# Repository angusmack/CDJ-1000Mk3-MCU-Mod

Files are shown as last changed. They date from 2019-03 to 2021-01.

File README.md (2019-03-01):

# Overview

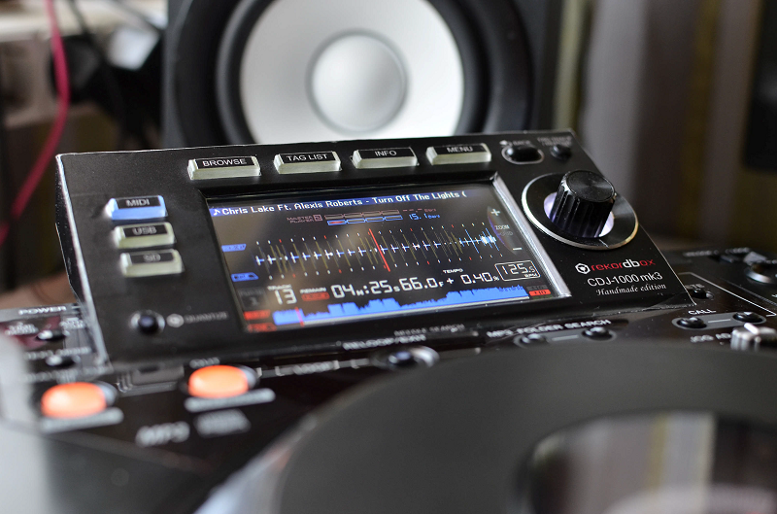
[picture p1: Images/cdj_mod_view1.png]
CDJ1000Mk3 MCU Mod


This is a modification to the CDJ-1000mk3 using an MCU, which allows SD-card playback of WAV files.

This firmware is for the F7 chip on the 32F746G DISCOVERY board.

This project was originally started by Andrei (DJ Greeb) in the [https://github.com/djgreeb/CDJ-1000mk3_new_life_project](repo).

This mod supports some Rekordbox functions, displaying of static and dynamic waveforms, audio interpolation process. 

I (Angus) have taken over the support of hosting the source code (that Andrei shared recently) and sharing the other supporting files needed such as STL and PCB for creating the finished product 

# Building the source
Use IDE uVision Keil ARM-MDK Professional and open project file F7.uvprojx in MDK_ARM folder.

Make sure you cut the tracks ULPI_1 and 13 as specified in the build manual before flashing.

# To do:
- AIFF support
- MP3 support
- USB playback
- Hot cues
- ?

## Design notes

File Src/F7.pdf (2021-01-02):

## F7 Project Configuration Report

# 1. Description

## 1.1. Project

Project Name | F7
Board Name | STM32F746G-DISCO
Generated with: | STM32CubeMX 4.22.0
Date | 04/26/2020

## 1.2. MCU

MCU Series | STM32F7
MCU Line | STM32F7x6
MCU name | STM32F746NGHx
MCU Package | TFBGA216
MCU Pin number | 216

# 2. Pinout Configuration

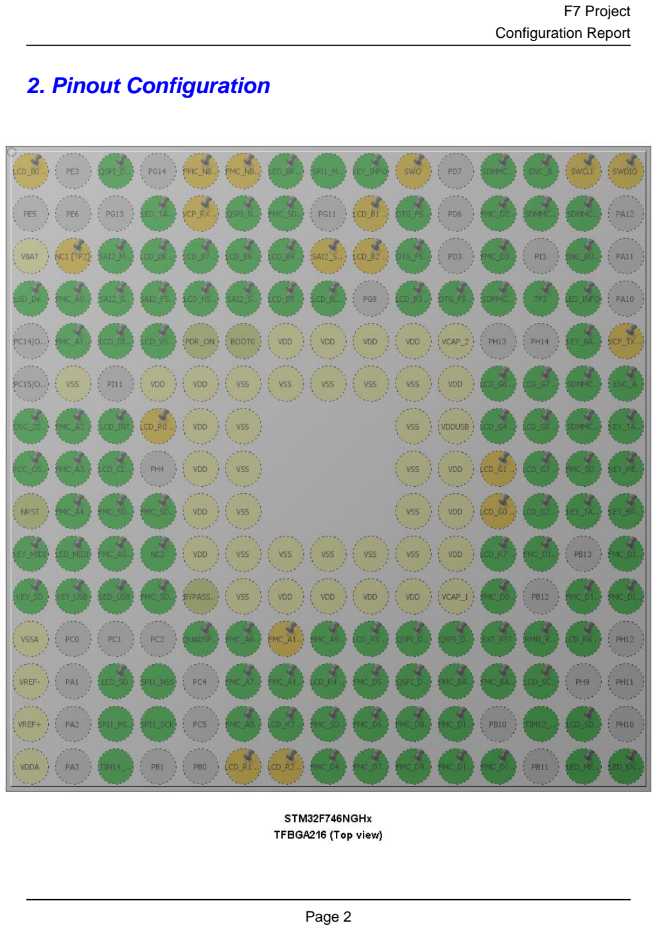
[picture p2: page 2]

# 3. Pins Configuration

Pin Number TFBGA216 | Pin Name (function after reset) | Pin Type | Alternate Function(s) | Label
A1 | PE4 * | I/O | LTDC_B0 | LCD_B0 [RK043FN48H-CT672B_B0]
A3 | PE2 | I/O | QUADSPI_BK1_IO2 | QSPI_D2 [N25Q128A13EF840E_DQ2 ]
A5 | PE1 * | I/O | FMC_NBL1 | FMC_NBL1 [MT48LC4M32B2B5-6A_DQM1]
A6 | PE0 * | I/O | FMC_NBL0 | FMC_NBL0 [MT48LC4M32B2B5-6A_DQM0]
A7 | PB8 ** | I/O | GPIO_Output | LED_BROWSE
A8 | PB5 | I/O | SPI1_MOSI
A9 | PB4 ** | I/O | GPIO_Input | KEY_INFO
A10 | PB3 * | I/O | SYS_JTDO-SWO | SWO
A12 | PC12 | I/O | SDMMC1_CK | SDMMC_CK
A13 | PA15 | I/O | GPIO_EXTI15 | ENC_B
A14 | PA14 * | I/O | SYS_JTCK-SWCLK | SWCLK
A15 | PA13 * | I/O | SYS_JTMS-SWDIO | SWDIO
B4 | PB9 ** | I/O | GPIO_Output | LED_TAG_LIST
B5 | PB7 * | I/O | USART1_RX | VCP_RX [STM32F103CBT6_PA2]
B6 | PB6 | I/O | QUADSPI_BK1_NCS | QSPI_NCS [N25Q128A13EF840E_S]
B7 | PG15 | I/O | FMC_SDNCAS | FMC_SDNCAS [MT48LC4M32B2B5-6A_CAS]
B9 | PJ13 * | I/O | LTDC_B1 | LCD_B1 [RK043FN48H-CT672B_B1]
B10 | PJ12 ** | I/O | GPIO_Input | OTG_FS_VBUS
B12 | PD0 | I/O | FMC_D2 | FMC_D2 [MT48LC4M32B2B5-6A_DQ2]
B13 | PC11 | I/O | SDMMC1_D3 | SDMMC_D3
B14 | PC10 | I/O | SDMMC1_D2 | SDMMC_D2
C1 | VBAT | Power
C2 | PI8 * | I/O | RTC_TS | NC1 [TP2]
C3 | PI4 | I/O | SAI2_MCLK_A | SAI2_MCLKA [WM8994ECS/R_MCLK1]

Pin Number TFBGA216 | Pin Name (function after reset) | Pin Type | Alternate Function(s) | Label
C4 | PK7 | I/O | LTDC_DE | LCD_DE [RK043FN48H-CT672B_DE]
C5 | PK6 | I/O | LTDC_B7 | LCD_B7 [RK043FN48H-CT672B_B7]
C6 | PK5 | I/O | LTDC_B6 | LCD_B6 [RK043FN48H-CT672B_B6]
C7 | PG12 | I/O | LTDC_B4 | LCD_B4 [RK043FN48H-CT672B_B4]
C8 | PG10 * | I/O | SAI2_SD_B | SAI2_SDB [WM8994ECS/R_ADCDAT1 ]
C9 | PJ14 * | I/O | LTDC_B2 | LCD_B2 [RK043FN48H-CT672B_B2]
C10 | PD5 ** | I/O | GPIO_Output | OTG_FS_PowerSwitchOn [STMPS2141STR_EN]
C12 | PD1 | I/O | FMC_D3 | FMC_D3 [MT48LC4M32B2B5-6A_DQ3]
C14 | PI2 ** | I/O | GPIO_Input | ENC_BUTTON
D1 | PC13 ** | I/O | GPIO_Input | uSD_Detect
D2 | PF0 | I/O | FMC_A0 | FMC_A0 [MT48LC4M32B2B5-6A_A0]
D3 | PI5 | I/O | SAI2_SCK_A | SAI2_SCKA [WM8994ECS/R_BCLK1]
D4 | PI7 | I/O | SAI2_FS_A | SAI2_FSA [WM8994ECS/R_LRCLK1]
D5 | PI10 | I/O | LTDC_HSYNC | LCD_HSYNC [RK043FN48H-CT672B_HSYNC]
D6 | PI6 | I/O | SAI2_SD_A | SAI2_SDA [WM8994ECS/R_DACDAT1 ]
D7 | PK4 | I/O | LTDC_B5 | LCD_B5 [RK043FN48H-CT672B_B5]
D8 | PK3 ** | I/O | GPIO_Output | LCD_BL_CTRL [STLD40DPUR_EN]
D10 | PJ15 | I/O | LTDC_B3 | LCD_B3 [RK043FN48H-CT672B_B3]
D11 | PD4 ** | I/O | GPIO_Input | OTG_FS_OverCurrent [STMPS2141STR_Fault]
D12 | PD2 | I/O | SDMMC1_CMD | SDMMC_D0
D13 | PH15 ** | I/O | GPIO_Input | TP3
D14 | PI1 ** | I/O | GPIO_Output | LED_INFO

Pin Number TFBGA216 | Pin Name (function after reset) | Pin Type | Alternate Function(s) | Label
E2 | PF1 | I/O | FMC_A1 | FMC_A1 [MT48LC4M32B2B5-6A_A1]
E3 | PI12 ** | I/O | GPIO_Output | LCD_DISP [RK043FN48H-CT672B_DISP]
E4 | PI9 | I/O | LTDC_VSYNC | LCD_VSYNC [RK043FN48H-CT672B_VSYNC]
E5 | PDR_ON | Reset
E6 | BOOT0 | Boot
E7 | VDD | Power
E8 | VDD | Power
E9 | VDD | Power
E10 | VDD | Power
E11 | VCAP_2 | Power
E14 | PI0 ** | I/O | GPIO_Input | KEY_BACK
E15 | PA9 * | I/O | USART1_TX | VCP_TX [STM32F103CBT6_PA3]
F2 | VSS | Power
F4 | VDD | Power
F5 | VDD | Power
F6 | VSS | Power
F7 | VSS | Power
F8 | VSS | Power
F9 | VSS | Power
F10 | VSS | Power
F11 | VDD | Power
F12 | PK1 | I/O | LTDC_G6 | LCD_G6 [RK043FN48H-CT672B_G6]
F13 | PK2 | I/O | LTDC_G7 | LCD_G7 [RK043FN48H-CT672B_G7]
F14 | PC9 | I/O | SDMMC1_D1
F15 | PA8 ** | I/O | GPIO_Input | ENC_A
G1 | PH0/OSC_IN | I/O | RCC_OSC_IN | OSC_25M [NZ2520SB-25.00M_OUT]
G2 | PF2 | I/O | FMC_A2 | FMC_A2 [MT48LC4M32B2B5-6A_A2]
G3 | PI13 | I/O | GPIO_EXTI13 | LCD_INT
G4 | PI15 * | I/O | LTDC_R0 | LCD_R0 [RK043FN48H-CT672B_R0]
G5 | VDD | Power
G6 | VSS | Power

Pin Number TFBGA216 | Pin Name (function after reset) | Pin Type | Alternate Function(s) | Label
G10 | VSS | Power
G11 | VDDUSB | Power
G12 | PJ11 | I/O | LTDC_G4 | LCD_G4 [RK043FN48H-CT672B_G4]
G13 | PK0 | I/O | LTDC_G5 | LCD_G5 [RK043FN48H-CT672B_G5]
G14 | PC8 | I/O | SDMMC1_D0
G15 | PC7 ** | I/O | GPIO_Input | KEY_TAG_LIST
H1 | PH1/OSC_OUT | I/O | RCC_OSC_OUT
H2 | PF3 | I/O | FMC_A3 | FMC_A3 [MT48LC4M32B2B5-6A_A3]
H3 | PI14 | I/O | LTDC_CLK | LCD_CLK [RK043FN48H-CT672B_CLK]
H5 | VDD | Power
H6 | VSS | Power
H10 | VSS | Power
H11 | VDD | Power
H12 | PJ8 * | I/O | LTDC_G1 | LCD_G1 [RK043FN48H-CT672B_G1]
H13 | PJ10 | I/O | LTDC_G3 | LCD_G3 [RK043FN48H-CT672B_G3]
H14 | PG8 | I/O | FMC_SDCLK | FMC_SDCLK [MT48LC4M32B2B5-6A_CLK]
H15 | PC6 ** | I/O | GPIO_Input | KEY_MENU
J1 | NRST | Reset
J2 | PF4 | I/O | FMC_A4 | FMC_A4 [MT48LC4M32B2B5-6A_A4]
J3 | PH5 | I/O | FMC_SDNWE | FMC_SDNME [MT48LC4M32B2B5-6A_WE]
J4 | PH3 | I/O | FMC_SDNE0 | FMC_SDNE0 [MT48LC4M32B2B5-6A_CS]
J5 | VDD | Power
J6 | VSS | Power
J10 | VSS | Power
J11 | VDD | Power
J12 | PJ7 * | I/O | LTDC_G0 | LCD_G0 [RK043FN48H-CT672B_G0]
J13 | PJ9 | I/O | LTDC_G2 | LCD_G2 [RK043FN48H-CT672B_G2]

Pin Number TFBGA216 | Pin Name (function after reset) | Pin Type | Alternate Function(s) | Label
J14 | PG7 ** | I/O | GPIO_Input | KEY_TAG_TRACK
J15 | PG6 ** | I/O | GPIO_Input | KEY_BROWSE
K1 | PF7 ** | I/O | GPIO_Input | KEY_MIDI
K2 | PF6 ** | I/O | GPIO_Output | LED_MIDI
K3 | PF5 | I/O | FMC_A5 | FMC_A5 [MT48LC4M32B2B5-6A_A5]
K4 | PH2 ** | I/O | GPIO_Input | NC2
K5 | VDD | Power
K6 | VSS | Power
K7 | VSS | Power
K8 | VSS | Power
K9 | VSS | Power
K10 | VSS | Power
K11 | VDD | Power
K12 | PJ6 | I/O | LTDC_R7 | LCD_R7 [RK043FN48H-CT672B_R7]
K13 | PD15 | I/O | FMC_D1 | FMC_D1 [MT48LC4M32B2B5-6A_DQ1]
K15 | PD10 | I/O | FMC_D15 | FMC_D15 [MT48LC4M32B2B5-6A_DQ15]
L1 | PF10 ** | I/O | GPIO_Input | KEY_SD
L2 | PF9 ** | I/O | GPIO_Input | KEY_USB
L3 | PF8 ** | I/O | GPIO_Output | LED_USB
L4 | PC3 | I/O | FMC_SDCKE0 | FMC_SDCKE0 [MT48LC4M32B2B5-6A_CKE]
L5 | BYPASS_REG | Reset
L6 | VSS | Power
L7 | VDD | Power
L8 | VDD | Power
L9 | VDD | Power
L10 | VDD | Power
L11 | VCAP_1 | Power
L12 | PD14 | I/O | FMC_D0 | FMC_D0 [MT48LC4M32B2B5-6A_DQ0]
L14 | PD9 | I/O | FMC_D14 | FMC_D14 [MT48LC4M32B2B5-6A_DQ14]

Pin Number TFBGA216 | Pin Name (function after reset) | Pin Type | Alternate Function(s) | Label
L15 | PD8 | I/O | FMC_D13 | FMC_D13 [MT48LC4M32B2B5-6A_DQ13]
M1 | VSSA | Power
M5 | PB2 | I/O | QUADSPI_CLK
M6 | PF12 | I/O | FMC_A6 | FMC_A6 [MT48LC4M32B2B5-6A_A6]
M7 | PG1 * | I/O | FMC_A11 | FMC_A11 [MT48LC4M32B2B5-6A_A11]
M8 | PF15 | I/O | FMC_A9 | FMC_A9 [MT48LC4M32B2B5-6A_A9]
M9 | PJ4 | I/O | LTDC_R5 | LCD_R5 [RK043FN48H-CT672B_R5]
M10 | PD12 | I/O | QUADSPI_BK1_IO1 | QSPI_D1 [N25Q128A13EF840E_DQ1 ]
M11 | PD13 | I/O | QUADSPI_BK1_IO3 | QSPI_D3 [N25Q128A13EF840E_DQ3 ]
M12 | PG3 ** | I/O | GPIO_Output | EXT_RST
M13 | PG2 ** | I/O | GPIO_Input | RMII_RXER
M14 | PJ5 | I/O | LTDC_R6 | LCD_R6 [RK043FN48H-CT672B_R6]
N1 | VREF- | Power
N3 | PA0/WKUP ** | I/O | GPIO_Output | LED_SD
N4 | PA4 | I/O | SPI1_NSS
N6 | PF13 | I/O | FMC_A7 | FMC_A7 [MT48LC4M32B2B5-6A_A7]
N7 | PG0 | I/O | FMC_A10 | FMC_A10 [MT48LC4M32B2B5-6A_A10]
N8 | PJ3 | I/O | LTDC_R4 | LCD_R4 [RK043FN48H-CT672B_R4]
N9 | PE8 | I/O | FMC_D5 | FMC_D5 [MT48LC4M32B2B5-6A_DQ5]
N10 | PD11 | I/O | QUADSPI_BK1_IO0 | QSPI_D0 [N25Q128A13EF840E_DQ0 ]
N11 | PG5 | I/O | FMC_BA1 | FMC_BA1 [MT48LC4M32B2B5-6A_BA1]

Pin Number TFBGA216 | Pin Name (function after reset) | Pin Type | Alternate Function(s) | Label
N12 | PG4 | I/O | FMC_BA0 | FMC_BA0 [MT48LC4M32B2B5-6A_BA0]
N13 | PH7 | I/O | I2C3_SCL | LCD_SCL [RK043FN48H-CT672B_SCL]
P1 | VREF+ | Power
P3 | PA6 | I/O | SPI1_MISO
P4 | PA5 | I/O | SPI1_SCK
P6 | PF14 | I/O | FMC_A8 | FMC_A8 [MT48LC4M32B2B5-6A_A8]
P7 | PJ2 | I/O | LTDC_R3 | LCD_R3 [RK043FN48H-CT672B_R3]
P8 | PF11 | I/O | FMC_SDNRAS | FMC_SDNRAS [MT48LC4M32B2B5-6A_RAS]
P9 | PE9 | I/O | FMC_D6 | FMC_D6 [MT48LC4M32B2B5-6A_DQ6]
P10 | PE11 | I/O | FMC_D8 | FMC_D8 [MT48LC4M32B2B5-6A_DQ8]
P11 | PE14 | I/O | FMC_D11 | FMC_D11 [MT48LC4M32B2B5-6A_DQ11]
P13 | PH6 | I/O | TIM12_CH1
P14 | PH8 | I/O | I2C3_SDA | LCD_SDA [RK043FN48H-CT672B_SDA]
R1 | VDDA | Power
R3 | PA7 | I/O | TIM14_CH1
R6 | PJ0 * | I/O | LTDC_R1 | LCD_R1 [RK043FN48H-CT672B_R1]
R7 | PJ1 * | I/O | LTDC_R2 | LCD_R2 [RK043FN48H-CT672B_R2]
R8 | PE7 | I/O | FMC_D4 | FMC_D4 [MT48LC4M32B2B5-6A_DQ4]
R9 | PE10 | I/O | FMC_D7 | FMC_D7 [MT48LC4M32B2B5-6A_DQ7]
R10 | PE12 | I/O | FMC_D9 | FMC_D9 [MT48LC4M32B2B5-6A_DQ9]

Pin Number TFBGA216 | Pin Name (function after reset) | Pin Type | Alternate Function(s) | Label
R11 | PE15 | I/O | FMC_D12 | FMC_D12 [MT48LC4M32B2B5-6A_DQ12]
R12 | PE13 | I/O | FMC_D10 | FMC_D10 [MT48LC4M32B2B5-6A_DQ10]
R14 | PB14 ** | I/O | GPIO_Output | LED_MENU
R15 | PB15 ** | I/O | GPIO_Output | LED_ENCODER

## ** The pin is affected with an I/O function * The pin is affected with a peripheral function but no peripheral mode is activated

# 4. Clock Tree Configuration

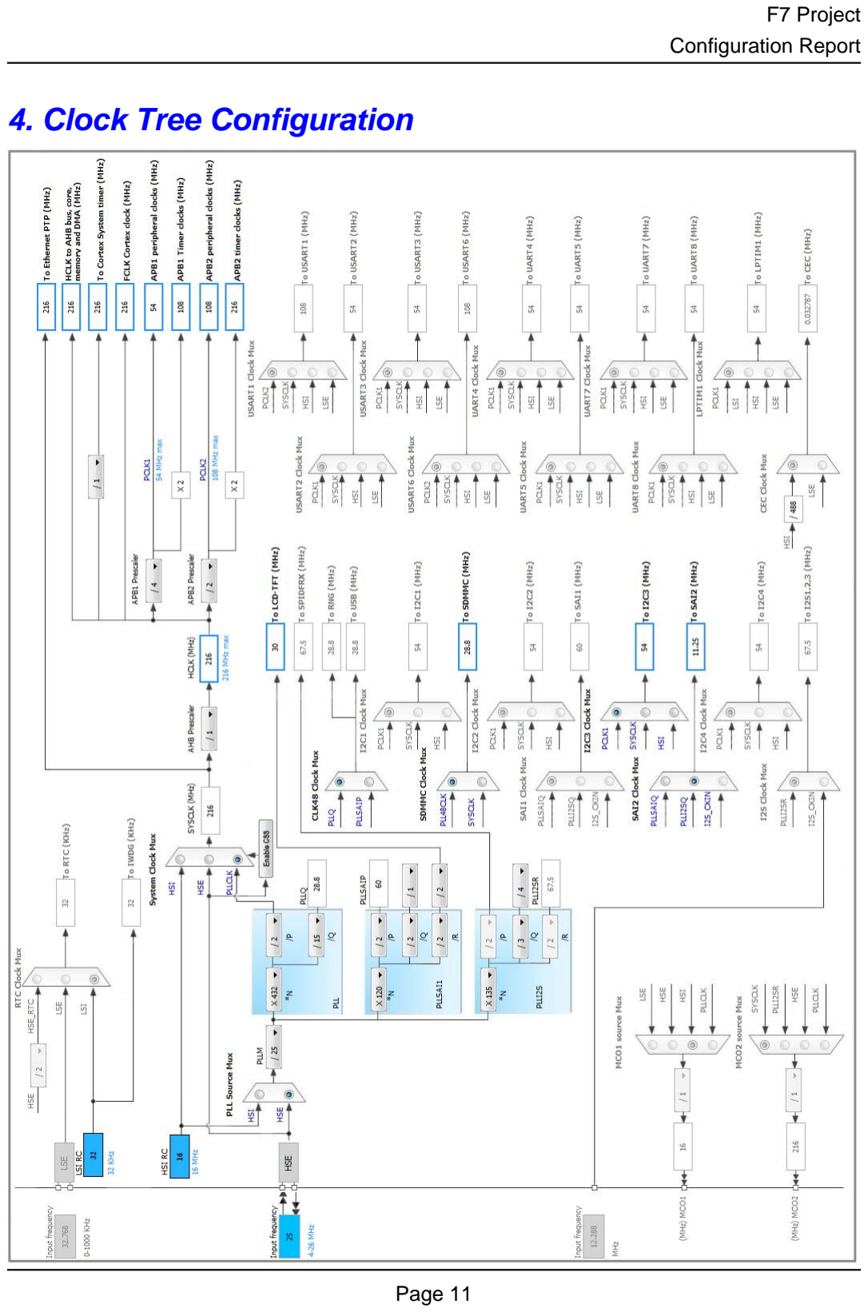
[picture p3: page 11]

# 5. IPs and Middleware Configuration

# 5.1. DMA2D

## mode: Activated

## 5.1.1. Parameter Settings:

### Basic Parameters:

Transfer Mode | Memory to Memory
Color Mode | ARGB8888
Output Offset | 0

### Foreground layer Configuration:

DMA2D Input Color Mode | ARGB8888
DMA2D ALPHA MODE | No modification of the alpha channel value
Input Alpha | 0
Input Offset | 0
DMA2D ALPHA Inversion | Regular Alpha
DMA2D Red and Blue swap | Regular mode (RGB or ARGB)

# 5.2. FMC

## SDRAM 1

## Clock and chip enable: SDCKE0+SDNE0 Internal bank number: 4 banks Address: 11 bits Data: 16 bits

## 5.2.1. SDRAM 1:

### SDRAM control:

Bank | SDRAM bank 1
Number of column address bits | 8 bits
Number of row address bits | 11 bits
CAS latency | 2 memory clock cycles *
Write protection | Disabled
SDRAM common clock | Disabled
SDRAM common burst read | Enabled *

SDRAM common read pipe delay | 0 HCLK clock cycle

### SDRAM timing in memory clock cycles:

Load mode register to active delay | 2 *
Exit self-refresh delay | 6 *
Self-refresh time | 4 *
SDRAM common row cycle delay | 6 *
Write recovery time | 2 *
SDRAM common row precharge delay | 2 *
Row to column delay | 2 *

# 5.3. I2C3

## I2C: I2C

## 5.3.1. Parameter Settings:

### Timing configuration:

I2C Speed Mode | Standard Mode
I2C Speed Frequency (KHz) | 100
Rise Time (ns) | 0
Fall Time (ns) | 0
Coefficient of Digital Filter | 0
Analog Filter | Enabled
Timing | 0x20404768 *

### Slave Features:

Clock No Stretch Mode | Disabled
General Call Address Detection | Disabled
Primary Address Length selection | 7-bit
Dual Address Acknowledged | Disabled
Primary slave address | 0

# 5.4. LTDC

## Display Type: RGB565 (16 bits)

## 5.4.1. Parameter Settings:

### Synchronization for Width:

Horizontal Synchronization Width | 41 *
Horizontal Back Porch | 13 *
Active Width | 480 *
Horizontal Front Porch | 32 *
HSync Width | 40
Accumulated Horizontal Back Porch Width | 53
Accumulated Active Width | 533
Total Width | 565

### Synchronization for Height:

Vertical Synchronization Height | 10 *
Vertical Back Porch | 2
Active Height | 272 *
Vertical Front Porch | 2
VSync Height | 9
Accumulated Vertical Back Porch Height | 11
Accumulated Active Height | 283
Total Height | 285

### Signal Polarity:

Horizontal Synchronization Polarity | Active Low
Vertical Synchronization Polarity | Active Low
Data Enable Polarity | Active Low
Pixel Clock Polarity | Normal Input

### BackGround Color:

Red | 0
Green | 0
Blue | 0

## 5.4.2. Layer Settings:

### BackGround Color:

Layer 0 - Blue | 0
Layer 0 - Green | 0
Layer 0 - Red | 0
Layer 1 - Blue | 0
Layer 1 - Green | 0
Layer 1 - Red | 0

### Windows Position:

Layer 0 - Window Horizontal Start | 0

Layer 0 - Window Horizontal Stop | 480 *
Layer 0 - Window Vertical Start | 0
Layer 0 - Window Vertical Stop | 272 *
Layer 1 - Window Horizontal Start | 0
Layer 1 - Window Horizontal Stop | 480 *
Layer 1 - Window Vertical Start | 0
Layer 1 - Window Vertical Stop | 272 *

### Pixel Parameters:

Layer 0 - Pixel Format | ARGB8888
Layer 1 - Pixel Format | ARGB8888

### Blending:

Layer 0 - Alpha constant for blending | 255 *
Layer 0 - Default Alpha value | 0
Layer 0 - Blending Factor1 | Alpha constant
Layer 0 - Blending Factor2 | Alpha constant
Layer 1 - Alpha constant for blending | 255 *
Layer 1 - Default Alpha value | 0
Layer 1 - Blending Factor1 | Alpha constant
Layer 1 - Blending Factor2 | Alpha constant

### Frame Buffer:

Layer 0 - Color Frame Buffer Start Adress | 0
Layer 0 - Color Frame Buffer Line Length (Image Width) | 0
Layer 0 - Color Frame Buffer Number of Lines (Image Height) | 0
Layer 1 - Color Frame Buffer Start Adress | 0
Layer 1 - Color Frame Buffer Line Length (Image Width) | 0
Layer 1 - Color Frame Buffer Number of Lines (Image Height) | 0

### Number of Layers:

Number of Layers | 2 layers

# 5.5. QUADSPI

## QuadSPI Mode: Bank1 with Quad SPI Lines

## 5.5.1. Parameter Settings:

### General Parameters:

Clock Prescaler | 1 *
Fifo Threshold | 4 *
Sample Shifting | Sample Shifting Half Cycle *
Flash Size | 23 *
Chip Select High Time | 2 Cycles *
Clock Mode | Low
Flash ID | Flash ID 1
Dual Flash | Disabled

# 5.6. RCC

## High Speed Clock (HSE): Crystal/Ceramic Resonator

## 5.6.1. Parameter Settings:

### System Parameters:

VDD voltage (V) | 3.3
Flash Latency(WS) | 7 WS (8 CPU cycle)

### RCC Parameters:

HSI Calibration Value | 16
TIM Prescaler Selection | Disabled
HSE Startup Timout Value (ms) | 100
LSE Startup Timout Value (ms) | 5000

### Power Parameters:

Power Over Drive | Enabled
Power Regulatror Voltage Scale | Power Regulator Voltage Scale 1

# 5.7. SAI2

## Mode: Master with Master Clock Out

## 5.7.1. Parameter Settings:

### SAI A:

Basic Parameters
Protocol | Free
Audio Mode | Master Transmit
Frame Length | 64 bits *

Data Size | 16 Bits *
Slot Size | DataSize
Output Mode | Stereo
Companding Mode | No companding mode
SAI SD Line Output Mode | Driven
Frame Parameters
First Bit | MSB First
Frame Synchro Active Level Length | 1
Frame Synchro Definition | Channel Identification *
Frame Synchro Polarity | Active Low
Frame Synchro Offset | Before First Bit *

Slot Parameters
First Bit Offset | 0
Number of Slots (only Even Values) | 2
Slot Active Final Value | 0x00000003 *
Slot Active | User Setting *
Slot 0 Active | true *
Slot 1 Active | true *

Clock Parameters
Master Clock Divider | Enabled
Audio Frequency | 44.1 KHz *
Real Audio Frequency | 43.945 KHz *
Error between Selected | -77.11 % *
Clock Strobing | Rising Edge *

Advanced Parameters
Fifo Threshold | Empty
Output Drive | Enabled *
Synchronization External | Disabled

# 5.8. SDMMC1

## Mode: SD 4 bits Wide bus

## 5.8.1. Parameter Settings:

### SDMMC parameters:

SDMMCCLK clock divide factor | 1 *

# 5.9. SPI1

## Mode: Full-Duplex Slave Hardware NSS Signal: Hardware NSS Input Signal

## 5.9.1. Parameter Settings:

### Basic Parameters:

Frame Format | Motorola
Data Size | 8 Bits *
First Bit | MSB First

### Clock Parameters:

Clock Polarity (CPOL) | High *
Clock Phase (CPHA) | 2 Edge *

### Advanced Parameters:

CRC Calculation | Disabled
NSS Signal Type | Input Hardware

# 5.10. SYS

## Timebase Source: SysTick

# 5.11. TIM1

## Clock Source : Internal Clock

## 5.11.1. Parameter Settings:

### Counter Settings:

Prescaler (PSC - 16 bits value) | 999 *
Counter Mode | Up
Counter Period (AutoReload Register - 16 bits value ) | 215 *
Internal Clock Division (CKD) | Division by 4 *
Repetition Counter (RCR - 16 bits value) | 0
auto-reload preload | Disable

### Trigger Output (TRGO) Parameters:

Master/Slave Mode | Disable (no sync between this TIM (Master) and its Slaves

Trigger Event Selection TRGO | Reset (UG bit from TIMx_EGR)
Trigger Event Selection TRGO2 | Reset (UG bit from TIMx_EGR)

# 5.12. TIM12

## mode: Clock Source Channel1: PWM Generation CH1

## 5.12.1. Parameter Settings:

### Counter Settings:

Prescaler (PSC - 16 bits value) | 24 *
Counter Mode | Up
Counter Period (AutoReload Register - 16 bits value ) | 255 *
Internal Clock Division (CKD) | Division by 4 *
auto-reload preload | Disable

### PWM Generation Channel 1:

Mode | PWM mode 1
Pulse (16 bits value) | 127 *
Fast Mode | Disable
CH Polarity | High

# 5.13. TIM14

## mode: Activated Channel1: PWM Generation CH1

## 5.13.1. Parameter Settings:

### Counter Settings:

Prescaler (PSC - 16 bits value) | 24 *
Counter Mode | Up
Counter Period (AutoReload Register - 16 bits value ) | 255 *
Internal Clock Division (CKD) | Division by 4 *
auto-reload preload | Disable

### PWM Generation Channel 1:

Mode | PWM mode 1

Pulse (16 bits value) | 200 *
Fast Mode | Disable
CH Polarity | High

# 5.14. FATFS

## mode: SD Card

## 5.14.1. Set Defines:

### Version:

FATFS version | R0.11

### Function Parameters:

FS_READONLY (Read-only mode) | Disabled
FS_MINIMIZE (Minimization level) | Disabled
USE_STRFUNC (String functions) | Enabled with LF -> CRLF conversion
USE_FIND (Find functions) | Disabled
USE_MKFS (Make filesystem function) | Enabled
USE_FASTSEEK (Fast seek function) | Enabled
USE_LABEL (Volume label functions) | Disabled
USE_FORWARD (Forward function) | Disabled

### Locale and Namespace Parameters:

CODE_PAGE (Code page on target) | Multilingual Latin 1 (OEM)
USE_LFN (Use Long Filename) | Enabled with static working buffer on the BSS *
MAX_LFN (Max Long Filename) | 255
LFN_UNICODE (Enable Unicode) | ANSI/OEM
STRF_ENCODE (Character encoding) | UTF-8
FS_RPATH (Relative Path) | Disabled

### Physical Drive Parameters:

VOLUMES (Logical drives) | 1
MAX_SS (Maximum Sector Size) | 4096 *
MIN_SS (Minimum Sector Size) | 512
MULTI_PARTITION (Volume partitions feature) | Disabled
USE_TRIM (Erase feature) | Disabled
FS_NOFSINFO (Force full FAT scan) | 0

### System Parameters:

FS_TINY (Tiny mode) | Disabled
FS_NORTC (Timestamp feature) | Dynamic timestamp
NORTC_YEAR (Year for timestamp) | 2015
NORTC_MON (Month for timestamp) | 6

NORTC_MDAY (Day for timestamp) | 4
WORD_ACCESS (Platform dependent access option) | Byte access
FS_REENTRANT (Re-Entrancy) | Disabled
FS_TIMEOUT (Timeout ticks) | 1000
SYNC_t (O/S sync object) | osSemaphoreId
FS_LOCK (Number of files opened simultaneously) | 2

## 5.14.2. IPs instances:

### SDIO/SDMMC:

SDMMC instance | SDMMC1

### * User modified value

# 6. System Configuration

# 6.1. GPIO configuration

IP | Pin | Signal | GPIO mode | GPIO pull/up pull down

## Max Speed

## User Label

FMC | PG15 | FMC_SDNCAS Alternate Function Push Pull | No pull-up and no pull-down | Very High | FMC_SDNCAS
[MT48LC4M32B2B5-
6A_CAS]
PD0 | FMC_D2 | Alternate Function Push Pull | No pull-up and no pull-down | Very High | FMC_D2
[MT48LC4M32B2B5-
6A_DQ2]
PD1 | FMC_D3 | Alternate Function Push Pull | No pull-up and no pull-down | Very High | FMC_D3
[MT48LC4M32B2B5-
6A_DQ3]
PF0 | FMC_A0 | Alternate Function Push Pull | No pull-up and no pull-down | Very High | FMC_A0
[MT48LC4M32B2B5-
6A_A0]
PF1 | FMC_A1 | Alternate Function Push Pull | No pull-up and no pull-down | Very High | FMC_A1
[MT48LC4M32B2B5-
6A_A1]
PF2 | FMC_A2 | Alternate Function Push Pull | No pull-up and no pull-down | Very High | FMC_A2
[MT48LC4M32B2B5-
6A_A2]
PF3 | FMC_A3 | Alternate Function Push Pull | No pull-up and no pull-down | Very High | FMC_A3
[MT48LC4M32B2B5-
6A_A3]
PG8 | FMC_SDCLK | Alternate Function Push Pull | No pull-up and no pull-down | Very High | FMC_SDCLK
[MT48LC4M32B2B5-
6A_CLK]
PF4 | FMC_A4 | Alternate Function Push Pull | No pull-up and no pull-down | Very High | FMC_A4
[MT48LC4M32B2B5-
6A_A4]
PH5 | FMC_SDNWE Alternate Function Push Pull | No pull-up and no pull-down | Very High | FMC_SDNME
[MT48LC4M32B2B5-
6A_WE]
PH3 | FMC_SDNE0 | Alternate Function Push Pull | No pull-up and no pull-down | Very High | FMC_SDNE0
[MT48LC4M32B2B5-
6A_CS]
PF5 | FMC_A5 | Alternate Function Push Pull | No pull-up and no pull-down | Very High | FMC_A5
[MT48LC4M32B2B5-
6A_A5]
PD15 | FMC_D1 | Alternate Function Push Pull | No pull-up and no pull-down | Very High | FMC_D1
[MT48LC4M32B2B5-
6A_DQ1]

IP | Pin | Signal | GPIO mode | GPIO pull/up pull down

## Max Speed

## User Label

PD10 | FMC_D15 | Alternate Function Push Pull | No pull-up and no pull-down | Very High | FMC_D15 [MT48LC4M32B2B5- 6A_DQ15]
PC3 | FMC_SDCKE0 Alternate Function Push Pull | No pull-up and no pull-down | Very High | FMC_SDCKE0
| | | | | [MT48LC4M32B2B5- 6A_CKE]
PD14 | FMC_D0 | Alternate Function Push Pull | No pull-up and no pull-down | Very High | FMC_D0 [MT48LC4M32B2B5- 6A_DQ0]
PD9 | FMC_D14 | Alternate Function Push Pull | No pull-up and no pull-down | Very High | FMC_D14 [MT48LC4M32B2B5- 6A_DQ14]
PD8 | FMC_D13 | Alternate Function Push Pull | No pull-up and no pull-down | Very High | FMC_D13 [MT48LC4M32B2B5- 6A_DQ13]
PF12 | FMC_A6 | Alternate Function Push Pull | No pull-up and no pull-down | Very High | FMC_A6 [MT48LC4M32B2B5- 6A_A6]
PF15 | FMC_A9 | Alternate Function Push Pull | No pull-up and no pull-down | Very High | FMC_A9 [MT48LC4M32B2B5- 6A_A9]
PF13 | FMC_A7 | Alternate Function Push Pull | No pull-up and no pull-down | Very High | FMC_A7 [MT48LC4M32B2B5- 6A_A7]
PG0 | FMC_A10 | Alternate Function Push Pull | No pull-up and no pull-down | Very High | FMC_A10 [MT48LC4M32B2B5- 6A_A10]
PE8 | FMC_D5 | Alternate Function Push Pull | No pull-up and no pull-down | Very High | FMC_D5 [MT48LC4M32B2B5- 6A_DQ5]
PG5 | FMC_BA1 | Alternate Function Push Pull | No pull-up and no pull-down | Very High | FMC_BA1 [MT48LC4M32B2B5- 6A_BA1]
PG4 | FMC_BA0 | Alternate Function Push Pull | No pull-up and no pull-down | Very High | FMC_BA0 [MT48LC4M32B2B5- 6A_BA0]
PF14 | FMC_A8 | Alternate Function Push Pull | No pull-up and no pull-down | Very High | FMC_A8 [MT48LC4M32B2B5- 6A_A8]
PF11 | FMC_SDNRAS Alternate Function Push Pull | No pull-up and no pull-down | Very High | FMC_SDNRAS
| | | | | [MT48LC4M32B2B5- 6A_RAS]
PE9 | FMC_D6 | Alternate Function Push Pull | No pull-up and no pull-down | Very High | FMC_D6 [MT48LC4M32B2B5- 6A_DQ6]
PE11 | FMC_D8 | Alternate Function Push Pull | No pull-up and no pull-down | Very High | FMC_D8 [MT48LC4M32B2B5-

IP | Pin | Signal | GPIO mode | GPIO pull/up pull down

## Max Speed

## User Label

6A_DQ8]
| PE14 | FMC_D11 | Alternate Function Push Pull | No pull-up and no pull-down | Very High | FMC_D11 [MT48LC4M32B2B5- 6A_DQ11]
| PE7 | FMC_D4 | Alternate Function Push Pull | No pull-up and no pull-down | Very High | FMC_D4 [MT48LC4M32B2B5- 6A_DQ4]
| PE10 | FMC_D7 | Alternate Function Push Pull | No pull-up and no pull-down | Very High | FMC_D7 [MT48LC4M32B2B5- 6A_DQ7]
| PE12 | FMC_D9 | Alternate Function Push Pull | No pull-up and no pull-down | Very High | FMC_D9 [MT48LC4M32B2B5- 6A_DQ9]
| PE15 | FMC_D12 | Alternate Function Push Pull | No pull-up and no pull-down | Very High | FMC_D12 [MT48LC4M32B2B5- 6A_DQ12]
| PE13 | FMC_D10 | Alternate Function Push Pull | No pull-up and no pull-down | Very High | FMC_D10 [MT48LC4M32B2B5- 6A_DQ10]
I2C3 | PH7 | I2C3_SCL | Alternate Function Open Drain | Pull-up | Very High
*
| | | | | | LCD_SCL [RK043FN48H- CT672B_SCL]
| PH8 | I2C3_SDA | Alternate Function Open Drain | Pull-up | Very High
*
| | | | | | LCD_SDA [RK043FN48H- CT672B_SDA]
LTDC | PK7 | LTDC_DE | Alternate Function Push Pull | No pull-up and no pull-down | Low | LCD_DE [RK043FN48H- CT672B_DE]
| PK6 | LTDC_B7 | Alternate Function Push Pull | No pull-up and no pull-down | Low | LCD_B7 [RK043FN48H- CT672B_B7]
| PK5 | LTDC_B6 | Alternate Function Push Pull | No pull-up and no pull-down | Low | LCD_B6 [RK043FN48H- CT672B_B6]
| PG12 | LTDC_B4 | Alternate Function Push Pull | No pull-up and no pull-down | Low | LCD_B4 [RK043FN48H- CT672B_B4]
PI10 | LTDC_HSYNC Alternate Function Push Pull | No pull-up and no pull-down | Low | LCD_HSYNC
| | | | | | [RK043FN48H- CT672B_HSYNC]
| PK4 | LTDC_B5 | Alternate Function Push Pull | No pull-up and no pull-down | Low | LCD_B5 [RK043FN48H- CT672B_B5]
| PJ15 | LTDC_B3 | Alternate Function Push Pull | No pull-up and no pull-down | Low | LCD_B3 [RK043FN48H- CT672B_B3]
PI9 | LTDC_VSYNC Alternate Function Push Pull | No pull-up and no pull-down | Low | LCD_VSYNC
| | | | | | [RK043FN48H- CT672B_VSYNC]
| PK1 | LTDC_G6 | Alternate Function Push Pull | No pull-up and no pull-down | Low | LCD_G6 [RK043FN48H- CT672B_G6]
| PK2 | LTDC_G7 | Alternate Function Push Pull | No pull-up and no pull-down | Low | LCD_G7 [RK043FN48H- CT672B_G7]

IP | Pin | Signal | GPIO mode | GPIO pull/up pull down

## Max Speed

## User Label

PJ11 | LTDC_G4 | Alternate Function Push Pull | No pull-up and no pull-down | Low | LCD_G4 [RK043FN48H-
CT672B_G4]
PK0 | LTDC_G5 | Alternate Function Push Pull | No pull-up and no pull-down | Low | LCD_G5 [RK043FN48H-
CT672B_G5]
PI14 | LTDC_CLK | Alternate Function Push Pull | No pull-up and no pull-down | Low | LCD_CLK [RK043FN48H-
CT672B_CLK]
PJ10 | LTDC_G3 | Alternate Function Push Pull | No pull-up and no pull-down | Low | LCD_G3 [RK043FN48H-
CT672B_G3]
PJ9 | LTDC_G2 | Alternate Function Push Pull | No pull-up and no pull-down | Low | LCD_G2 [RK043FN48H-
CT672B_G2]
PJ6 | LTDC_R7 | Alternate Function Push Pull | No pull-up and no pull-down | Low | LCD_R7 [RK043FN48H-
CT672B_R7]
PJ4 | LTDC_R5 | Alternate Function Push Pull | No pull-up and no pull-down | Low | LCD_R5 [RK043FN48H-
CT672B_R5]
PJ5 | LTDC_R6 | Alternate Function Push Pull | No pull-up and no pull-down | Low | LCD_R6 [RK043FN48H-
CT672B_R6]
PJ3 | LTDC_R4 | Alternate Function Push Pull | No pull-up and no pull-down | Low | LCD_R4 [RK043FN48H-
CT672B_R4]
PJ2 | LTDC_R3 | Alternate Function Push Pull | No pull-up and no pull-down | Low | LCD_R3 [RK043FN48H-
CT672B_R3]
QUADSPI | PE2 | QUADSPI_BK1_I
O2
Alternate Function Push Pull | No pull-up and no pull-down | Very High
*

QSPI_D2
[N25Q128A13EF840E_DQ
2]
PB6 QUADSPI_BK1_
NCS
Alternate Function Push Pull | No pull-up and no pull-down | Very High
*

QSPI_NCS
[N25Q128A13EF840E_S]
PB2 | QUADSPI_CLK Alternate Function Push Pull | No pull-up and no pull-down | Very High
*

PD12 QUADSPI_BK1_I
O1
Alternate Function Push Pull | No pull-up and no pull-down | Very High
*

QSPI_D1
[N25Q128A13EF840E_DQ
1]
PD13 QUADSPI_BK1_I
O3
Alternate Function Push Pull | No pull-up and no pull-down | Very High
*

QSPI_D3
[N25Q128A13EF840E_DQ
3]
PD11 QUADSPI_BK1_I
O0
Alternate Function Push Pull | No pull-up and no pull-down | Very High
*

QSPI_D0
[N25Q128A13EF840E_DQ
0]
RCC PH0/OSC_I
N
RCC_OSC_IN | n/a | n/a | n/a | OSC_25M [NZ2520SB-
25.00M_OUT]
PH1/OSC_O
UT
RCC_OSC_OUT | n/a | n/a | n/a
SAI2 | PI4 | SAI2_MCLK_A Alternate Function Push Pull | No pull-up and no pull-down | Low | SAI2_MCLKA
[WM8994ECS/R_MCLK1]
PI5 | SAI2_SCK_A | Alternate Function Push Pull | No pull-up and no pull-down | Low | SAI2_SCKA
[WM8994ECS/R_BCLK1]

IP | Pin | Signal | GPIO mode | GPIO pull/up pull down | Max Speed | User Label
| PI7 | SAI2_FS_A | Alternate Function Push Pull | No pull-up and no pull-down | Low | SAI2_FSA [WM8994ECS/R_LRCLK1]
| PI6 | SAI2_SD_A | Alternate Function Push Pull | No pull-up and no pull-down | Low | SAI2_SDA [WM8994ECS/R_DACDAT 1]
SDMMC1 | PC12 | SDMMC1_CK | Alternate Function Push Pull | No pull-up and no pull-down | Very High | SDMMC_CK
| PC11 | SDMMC1_D3 | Alternate Function Push Pull | No pull-up and no pull-down | Very High | SDMMC_D3
| PC10 | SDMMC1_D2 | Alternate Function Push Pull | No pull-up and no pull-down | Very High | SDMMC_D2
| PD2 | SDMMC1_CMD | Alternate Function Push Pull | No pull-up and no pull-down | Very High | SDMMC_D0
| PC9 | SDMMC1_D1 | Alternate Function Push Pull | No pull-up and no pull-down | Very High
| PC8 | SDMMC1_D0 | Alternate Function Push Pull | No pull-up and no pull-down | Very High
SPI1 | PB5 | SPI1_MOSI | Alternate Function Push Pull | No pull-up and no pull-down | Very High *
| PA4 | SPI1_NSS | Alternate Function Push Pull | No pull-up and no pull-down | Very High *
| PA6 | SPI1_MISO | Alternate Function Push Pull | No pull-up and no pull-down | Very High *
| PA5 | SPI1_SCK | Alternate Function Push Pull | No pull-up and no pull-down | Very High *
TIM12 | PH6 | TIM12_CH1 | Alternate Function Push Pull | No pull-up and no pull-down | Low
TIM14 | PA7 | TIM14_CH1 | Alternate Function Push Pull | No pull-up and no pull-down | Low
| PE4 | LTDC_B0 | Alternate Function Push Pull | No pull-up and no pull-down | Low | LCD_B0 [RK043FN48H-CT672B_B0]
| PE1 | FMC_NBL1 | Alternate Function Push Pull | No pull-up and no pull-down | Very High | FMC_NBL1 [MT48LC4M32B2B5-6A_DQM1]
| PE0 | FMC_NBL0 | Alternate Function Push Pull | No pull-up and no pull-down | Very High | FMC_NBL0 [MT48LC4M32B2B5-6A_DQM0]
| PB3 | SYS_JTDO-SWO | n/a | n/a | n/a | SWO
| PA14 | SYS_JTCK-SWCLK | n/a | n/a | n/a | SWCLK
| PA13 | SYS_JTMS-SWDIO | n/a | n/a | n/a | SWDIO
| PB7 | USART1_RX | Alternate Function Push Pull | No pull-up and no pull-down | Low | VCP_RX [STM32F103CBT6_PA2]
| PJ13 | LTDC_B1 | Alternate Function Push Pull | No pull-up and no pull-down | Low | LCD_B1 [RK043FN48H-CT672B_B1]
| PI8 | RTC_TS | n/a | n/a | n/a | NC1 [TP2]
| PG10 | SAI2_SD_B | Alternate Function Push Pull | No pull-up and no pull-down | Low | SAI2_SDB [WM8994ECS/R_ADCDAT 1]

Single
Mapped
Signals

IP | Pin | Signal | GPIO mode | GPIO pull/up pull down | Max Speed | User Label
| PJ14 | LTDC_B2 | Alternate Function Push Pull | No pull-up and no pull-down | Low | LCD_B2 [RK043FN48H-CT672B_B2]
| PA9 | USART1_TX | Alternate Function Push Pull | No pull-up and no pull-down | Low | VCP_TX [STM32F103CBT6_PA3]
| PI15 | LTDC_R0 | Alternate Function Push Pull | No pull-up and no pull-down | Low | LCD_R0 [RK043FN48H-CT672B_R0]
| PJ8 | LTDC_G1 | Alternate Function Push Pull | No pull-up and no pull-down | Low | LCD_G1 [RK043FN48H-CT672B_G1]
| PJ7 | LTDC_G0 | Alternate Function Push Pull | No pull-up and no pull-down | Low | LCD_G0 [RK043FN48H-CT672B_G0]
| PG1 | FMC_A11 | Alternate Function Push Pull | No pull-up and no pull-down | Very High | FMC_A11 [MT48LC4M32B2B5-6A_A11]
| PJ0 | LTDC_R1 | Alternate Function Push Pull | No pull-up and no pull-down | Low | LCD_R1 [RK043FN48H-CT672B_R1]
| PJ1 | LTDC_R2 | Alternate Function Push Pull | No pull-up and no pull-down | Low | LCD_R2 [RK043FN48H-CT672B_R2]
GPIO | PB8 | GPIO_Output | Output Push Pull | No pull-up and no pull-down | Low | LED_BROWSE
PB4 | GPIO_Input | Input mode | Pull-up * | n/a | KEY_INFO
PA15 | GPIO_EXTI15 | External Interrupt Mode with Falling edge trigger detection | Pull-up * | n/a | ENC_B
PB9 | GPIO_Output | Output Push Pull | No pull-up and no pull-down | Low | LED_TAG_LIST
PJ12 | GPIO_Input | Input mode | No pull-up and no pull-down | n/a | OTG_FS_VBUS
PD5 | GPIO_Output | Output Push Pull | No pull-up and no pull-down | Low | OTG_FS_PowerSwitchOn [STMPS2141STR_EN]
PI2 | GPIO_Input | Input mode | Pull-up * | n/a | ENC_BUTTON
PC13 | GPIO_Input | Input mode | No pull-up and no pull-down | n/a | uSD_Detect
PK3 | GPIO_Output | Output Push Pull | No pull-up and no pull-down | Low | LCD_BL_CTRL [STLD40DPUR_EN]
PD4 | GPIO_Input | Input mode | No pull-up and no pull-down | n/a | OTG_FS_OverCurrent [STMPS2141STR_Fault]
PH15 | GPIO_Input | Input mode | No pull-up and no pull-down | n/a | TP3
PI1 | GPIO_Output | Output Push Pull | No pull-up and no pull-down | Low | LED_INFO
PI12 | GPIO_Output | Output Push Pull | No pull-up and no pull-down | Low | LCD_DISP [RK043FN48H-CT672B_DISP]
PI0 | GPIO_Input | Input mode | Pull-up * | n/a | KEY_BACK
PA8 | GPIO_Input | Input mode | Pull-up * | n/a | ENC_A
PI13 | GPIO_EXTI13 | External Event Mode with Rising edge trigger detection * | No pull-up and no pull-down | n/a | LCD_INT
PC7 | GPIO_Input | Input mode | No pull-up and no pull-down | n/a | KEY_TAG_LIST

IP | Pin | Signal | GPIO mode | GPIO pull/up pull down | Max Speed | User Label
| PC6 | GPIO_Input | Input mode | Pull-up * | n/a | KEY_MENU
| PG7 | GPIO_Input | Input mode | Pull-up * | n/a | KEY_TAG_TRACK
| PG6 | GPIO_Input | Input mode | Pull-up * | n/a | KEY_BROWSE
| PF7 | GPIO_Input | Input mode | Pull-up * | n/a | KEY_MIDI
| PF6 | GPIO_Output | Output Push Pull | No pull-up and no pull-down | Low | LED_MIDI
| PH2 | GPIO_Input | Input mode | No pull-up and no pull-down | n/a | NC2
| PF10 | GPIO_Input | Input mode | Pull-up * | n/a | KEY_SD
| PF9 | GPIO_Input | Input mode | Pull-up * | n/a | KEY_USB
| PF8 | GPIO_Output | Output Push Pull | No pull-up and no pull-down | Low | LED_USB
| PG3 | GPIO_Output | Output Push Pull | No pull-up and no pull-down | Low | EXT_RST
| PG2 | GPIO_Input | Input mode | No pull-up and no pull-down | n/a | RMII_RXER
| PA0/WKUP | GPIO_Output | Output Push Pull | No pull-up and no pull-down | Low | LED_SD
| PB14 | GPIO_Output | Output Push Pull | No pull-up and no pull-down | Low | LED_MENU
| PB15 | GPIO_Output | Output Push Pull | No pull-up and no pull-down | Low | LED_ENCODER

# 6.2. DMA configuration

DMA request | Stream | Direction | Priority
SPI1_RX | DMA2_Stream0 | Peripheral To Memory | Very High *
SPI1_TX | DMA2_Stream5 | Memory To Peripheral | Very High *
MEMTOMEM | DMA2_Stream1 | Memory To Memory | Medium *

## SPI1_RX: DMA2_Stream0 DMA request Settings:

Mode: | Circular *
Use fifo: | Disable
Peripheral Increment: | Disable
Memory Increment: | Enable *
Peripheral Data Width: | Byte
Memory Data Width: | Byte

## SPI1_TX: DMA2_Stream5 DMA request Settings:

Mode: | Circular *
Use fifo: | Disable
Peripheral Increment: | Disable
Memory Increment: | Enable *
Peripheral Data Width: | Byte
Memory Data Width: | Byte

## MEMTOMEM: DMA2_Stream1 DMA request Settings:

Mode: | Normal
Use fifo: | Enable *
FIFO Threshold: | Full
Src Memory Increment: | Enable *
Dst Memormy Increment: | Enable *
Src Memory Data Width: | Byte
Dst Memormy Data Width: | Byte
Src Memory Burst Size: | Single
Dst Memormy Burst Size: | Single

# 6.3. NVIC configuration

Interrupt Table | Enable | Preenmption Priority | SubPriority
Non maskable interrupt | true | 0 | 0
Hard fault interrupt | true | 0 | 0
Memory management fault | true | 0 | 0
Pre-fetch fault, memory access fault | true | 0 | 0
Undefined instruction or illegal state | true | 0 | 0
System service call via SWI instruction | true | 0 | 0
Debug monitor | true | 0 | 0
Pendable request for system service | true | 0 | 0
System tick timer | true | 0 | 0
TIM1 update interrupt and TIM10 global interrupt | true | 5 | 0
EXTI line[15:10] interrupts | true | 2 | 0
DMA2 stream0 global interrupt | true | 3 | 0
DMA2 stream5 global interrupt | true | 3 | 0
SAI2 global interrupt | true | 1 | 0
PVD interrupt through EXTI line 16 | unused
Flash global interrupt | unused
RCC global interrupt | unused
TIM1 break interrupt and TIM9 global interrupt | unused
TIM1 trigger and commutation interrupts and TIM11 global interrupt | unused
TIM1 capture compare interrupt | unused
SPI1 global interrupt | unused
TIM8 break interrupt and TIM12 global interrupt | unused
TIM8 trigger and commutation interrupts and TIM14 global interrupt | unused
FMC global interrupt | unused
SDMMC1 global interrupt | unused
DMA2 stream1 global interrupt | unused
I2C3 event interrupt | unused
I2C3 error interrupt | unused
FPU global interrupt | unused
LTDC global interrupt | unused
LTDC global error interrupt | unused
DMA2D global interrupt | unused
QUADSPI global interrupt | unused

### * User modified value

# 7. Power Consumption Calculator report

### 7.1. Microcontroller Selection

Series | STM32F7
Line | STM32F7x6
MCU | STM32F746NGHx
Datasheet | 027590_Rev4

### 7.2. Parameter Selection

Temperature | 25
Vdd | 3.3

# 8. Software Project

## 8.1. Project Settings

Name | Value
Project Name | F7
Project Folder | C:\Keil_v5\My_Project\F7 XDJ_PANEL
Toolchain / IDE | MDK-ARM V5
Firmware Package Name and Version | STM32Cube FW_F7 V1.7.0

## 8.2. Code Generation Settings

Name | Value
STM32Cube Firmware Library Package | Copy all used libraries into the project folder
Generate peripheral initialization as a pair of '.c/.h' files | Yes
Backup previously generated files when re-generating | No
Delete previously generated files when not re-generated | Yes
Set all free pins as analog (to optimize the power consumption) | No

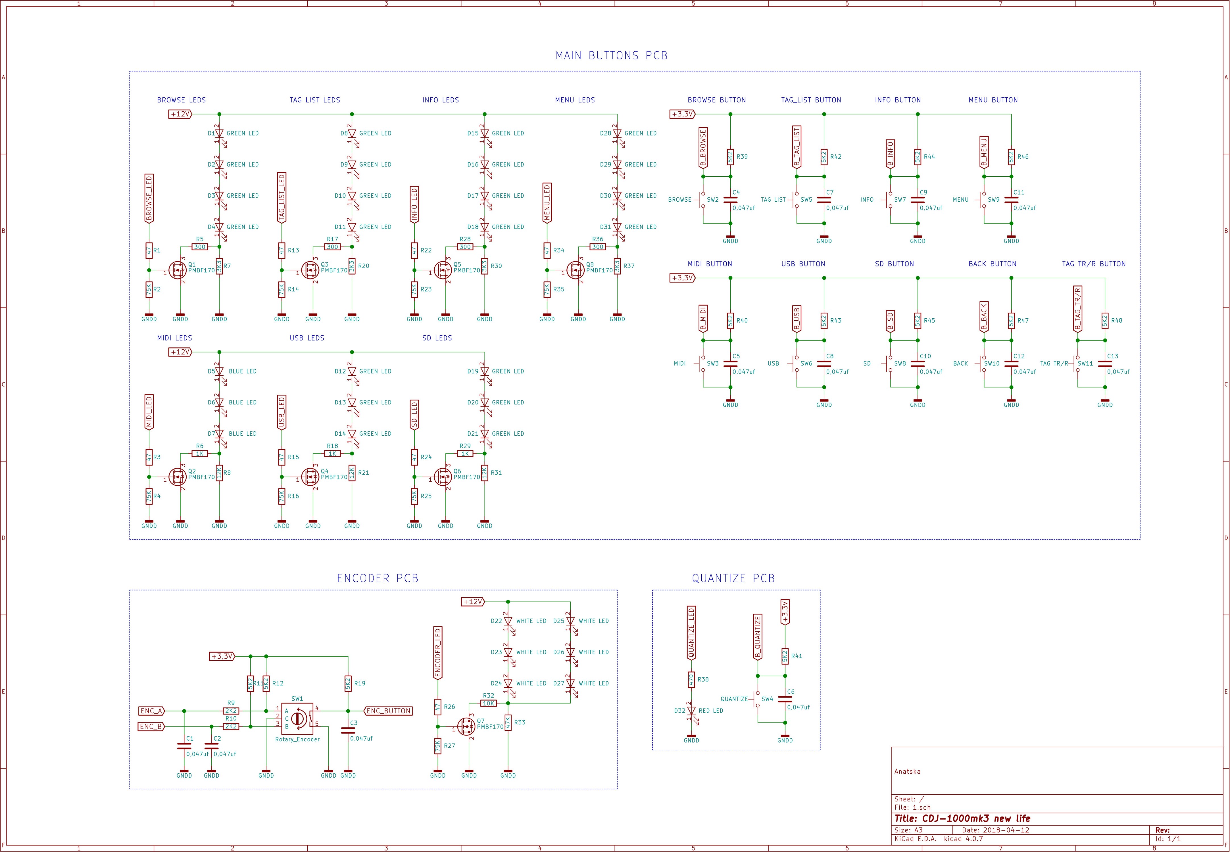
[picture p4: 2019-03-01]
Hardware/Schematic/sch buttons.jpg

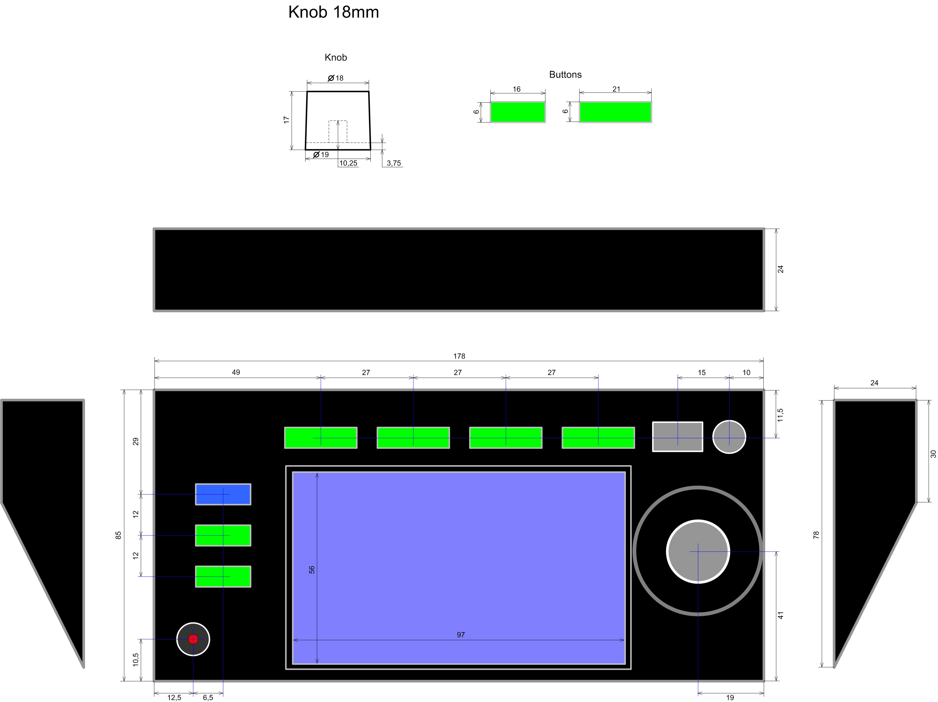
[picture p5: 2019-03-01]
Hardware/Drawing/CDJ model.jpg

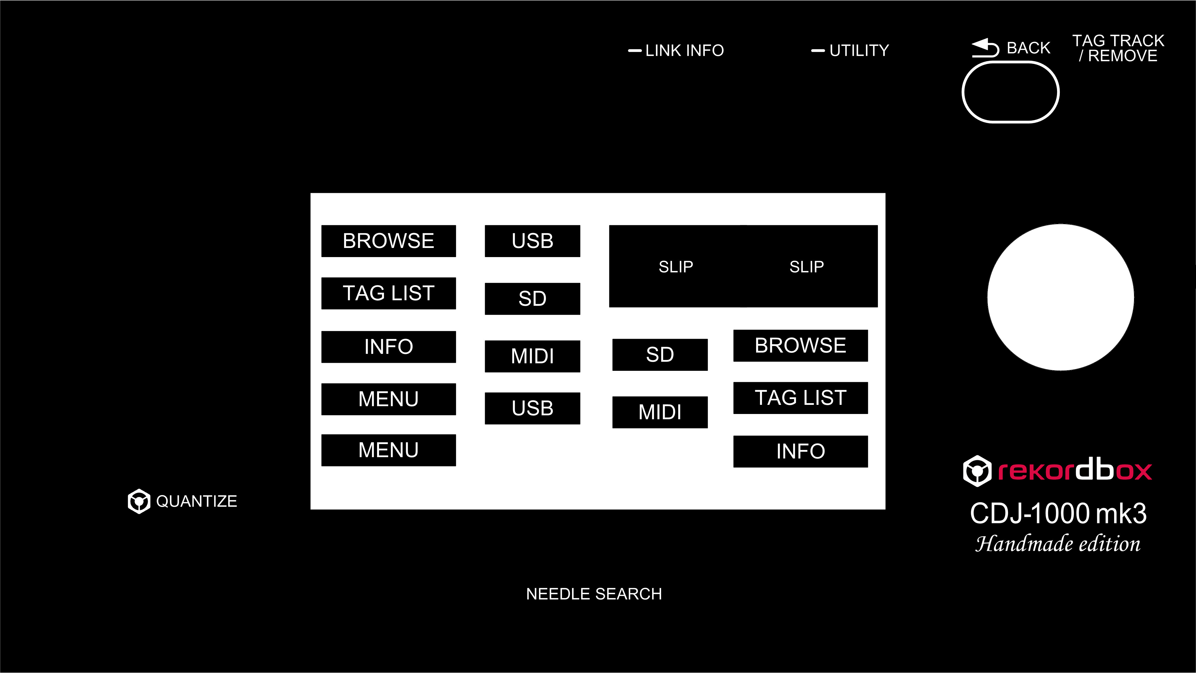
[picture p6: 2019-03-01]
Hardware/Stickers/LABEL_2.jpg

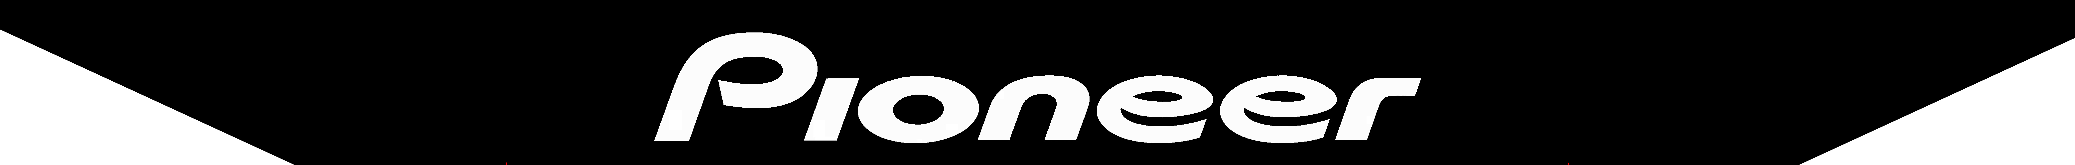
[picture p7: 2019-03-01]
Hardware/Stickers/LABEL_1.jpg

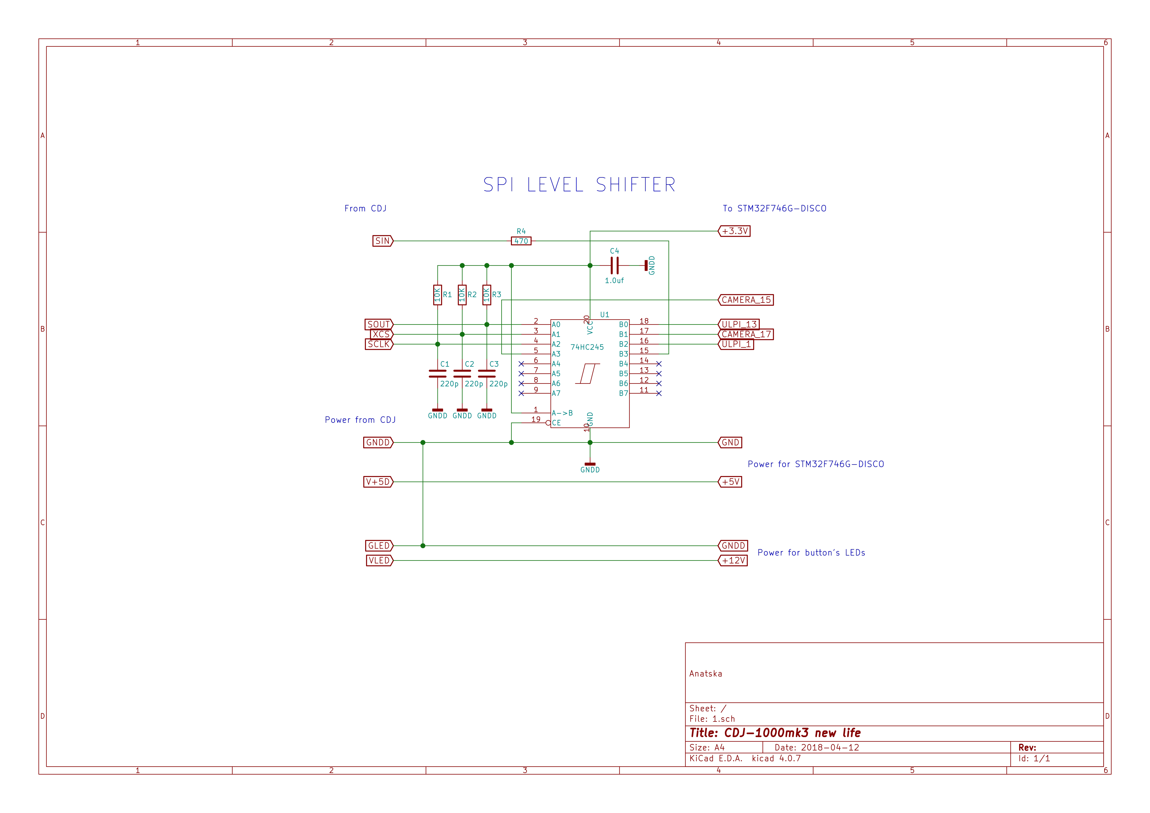
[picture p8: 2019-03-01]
Hardware/Schematic/sch mini board.jpg

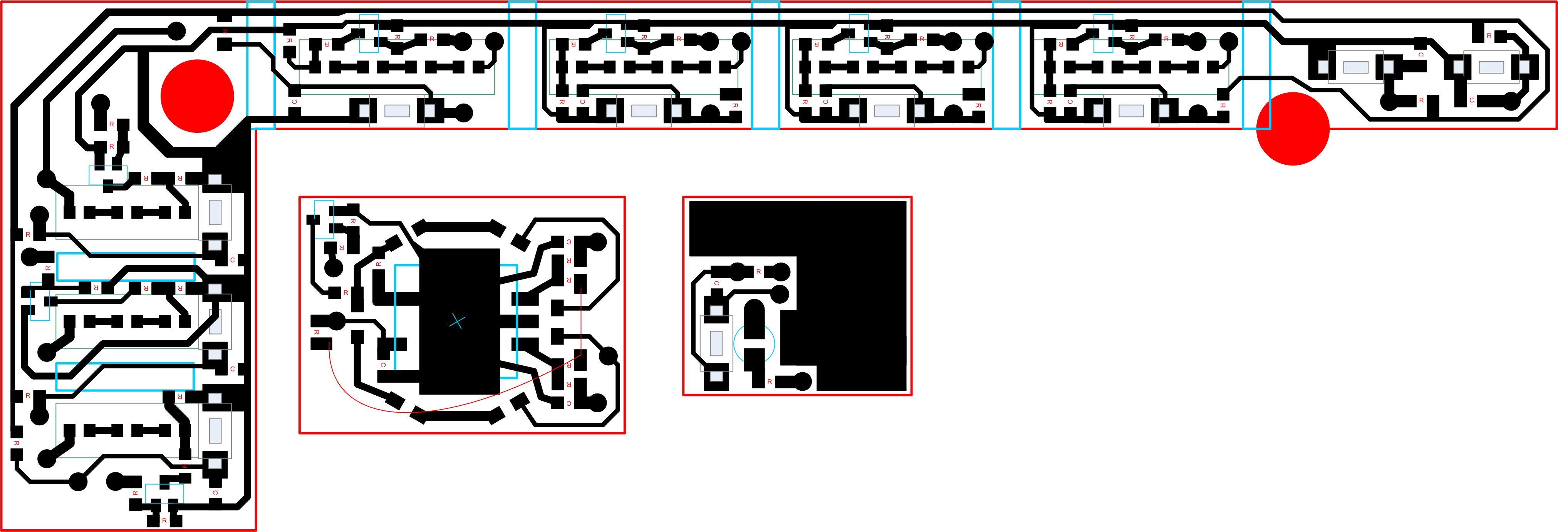
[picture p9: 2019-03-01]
Hardware/PCB/Key_board PCB.jpg

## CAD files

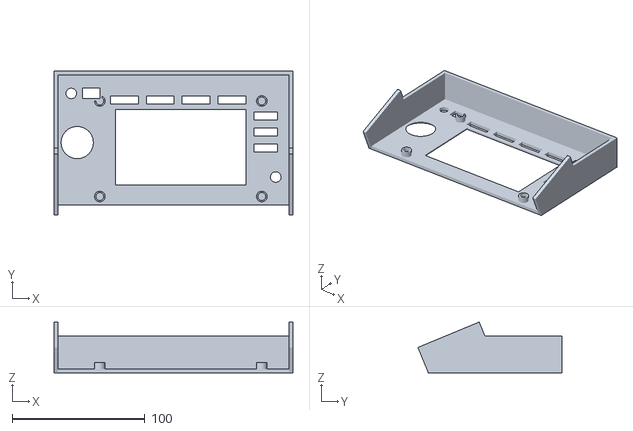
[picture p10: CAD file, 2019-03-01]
Hardware/Case/Case_Black.stl
180.0 x 108.7 x 38.3

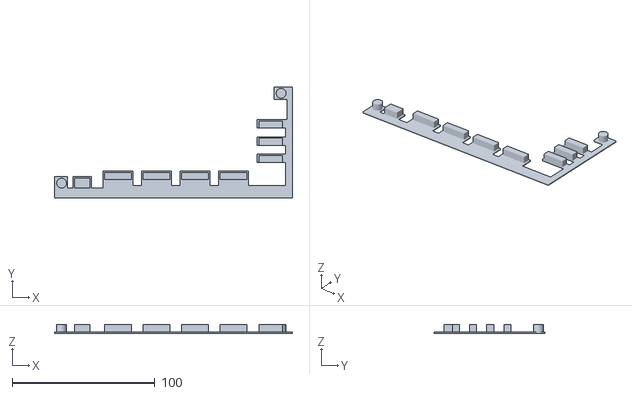
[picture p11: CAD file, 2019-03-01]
Hardware/Case/Buttons_Clear.stl
167.0 x 78.0 x 6.00

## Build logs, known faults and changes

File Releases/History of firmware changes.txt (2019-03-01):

//	ver. 0.61a
//		- optimized browser function
//		- added dark_green color in browser for text on white line cursor 
//	ver. 0.62a
//		- optimized DATABASE_PARSER finction
//		- DATABASE_PARSER using WFORMDYNAMIC massive only 
//	ver. 0.63a
//		- optimized LOAD_TRACK function. Now the PCM[] massive is not used.
//		- PCM[] converted in uint16_t
//		- optimized audio processing for new uint16_t PCM[]. Now the calculation of 1 sample is 5us instead of 7.5us 
//	ver. 0.64a
//		- fixed joint in circular buffer in audio processing
//		- optimized ring buffer size for increased audio processing performance
//	ver. 0.65a
//		- optimized audio processing (read SDRAM). Now the calculation of 1 sample is 4us 
//	 	- added SD_LED blink
//		- added encoder blink when loading track
//	ver. 0.66a
//		- added touch screen control
//	ver. 0.67a
//		- added basic function needle search
//		- fixed function BSP_LCD_DisplayStringAt. 
//		-	added TRANSPARENT_MODE for text. 
//		- changed method of determination the font with dynamic width (Font15P) and other fonts with static width.  
//		- optimized touch controller driver
//		- create audioparcer for SEEK function
//	ver. 0.68a
//		- added QSPI flash support
//		- added animation startup logo
//	ver. 0.69a
//		- added REKORDBOX logo on startup
//		- added tag list 
//		- added internal function for RedrawWaveforms process 
//	ver. 0.70a
//		- added INFO mode in BROWSER and TAG LIST menu
//		- added internal functions for optimize code
//	ver. 0.71a
//		- improved the functionality of the TAG LIST menu
//	ver. 0.72a
//		- added symbol red check mark for TAG LIST
//		- improved the functionality of the TAG LIST (added TAG TRACK/REMOVE button)
//		- bugs fixes internal functions browser and tag list
//		- bugs fixes NAVIGATOR function
//		- added loading track from TAG LIST
//	ver. 0.73a
//		- added UTILITY window
//		- added long press MENU button for entering to UTILITY
//		- fixed check WAV header
//		-	optimized process add/delete tracks in TAG LIST
//	ver. 0.74a
//		- added SPI transfer for CDJ-1000mk3 panel
//	ver. 0.75a
//		- added reading cues and memory pionts from ANLZXXXX.DAT
//		- fixed bug SPI DMA (see note*) 
//	ver. 0.76a
//		- added PLAY, TEMPO, TEMPO RESET, JOG MODE buttons
//		- added pitch slider 4 ranges
//		- added calculation tempo and bpm after pitch change
//	ver. 0.77a
//		- added PLAY blink led, CUE led
//		- improved jog vinyl mode (inertial process)
//		- added TRACK SEARCH buttons
//		- improved ShowTempo function
//		- added TIME MODE button, REMAIN MODE
//		- added CDJ JOG MODE work
//		- optimized pitch bend coeficients aka CDJ-1000mk3
//		- optimized VINYL MODE precision jog step
//	ver. 0.78a
//		- improved static scroll UI
//		- added BEATGRID massive
//		- shift up 1px static information, static waveform 
//		- beatgrid support
//		- improved Phase Meter
//	ver. 0.79a
//		- improved BPM calculating after pitch change
//		- added BPMGRID for tracks with variable BPM 
//	ver. 0.80a
//		- added Font13D for phase bars
//		- added slip mode marker on jog display
//		- added master player ICON
//		- added slip mode red button and slip mode jog illumination
//		- fixed bug spin jog at maximum speed (variable overflow)
//		- added first SLIP MODE functions with audio processing
//		- added animation icon and gradient for phase bars
//		- improved jog pitch bend in reverse mode
//		- improved jog in slip mode
//	ver. 0.81a
//		- added CUE blink
//		- improved time mode button code
//		- added VINYL RELEASE/START and TOUCH/BREAKE mode 
//		-	optimized SPI-DMA transfer process
//		-	optimized potenciometer's curve for VINYL RELEASE/START and TOUCH/BREAKE mode
//	ver. 0.82a
//		- added track nubmer and status (playing or played) in INFO mode
//		- added filling buffer step sequencer for optimize time gaps
//		- fixed filling buffer step sequencer algoritm
//	ver. 0.83a
//		- improved the work of the function of static and dynamic waveforms
//		- added "remain/foward time style" for progress bar
//	ver. 0.84b
//		- added blink progress bar when the remaining time is less than 30sec
//		- fixed DrawMinuteMarkers function
//		- improved performance static and dynamic waveforms (added ForceDrawVLine function)
//		- added checking device UID 
//		- fixed fatal error when deleting a track from an empty tag list
//		- the first addition of a function CUE audio
//	ver. 0.85b
//		- added CUE button process
//		- improved CUE audio process
//		- optimized pitch bend coefficients
//		- added loading of Hot Cues and Memory Cues attributes
//	ver. 0.86b
//		- added MEMORY CUE calling
//		- bugs fixes calling CUEs when jog in CDJ mode

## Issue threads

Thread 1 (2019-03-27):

Digital audio noise in end track

fabiodj2, 2019-03-27:
Hello everyone ... I've done my design step and it's almost all working ...

I am printing the case for the STM board and very eager to get everything ready. I was testing all the functions and I noticed a big one, I believe that it could be some problem in my STM, so I would like you to do a test in the same way that I like in the video below:

https://youtu.be/iJTq9NwelFo

The problem is a digital noise whenever the Track is finished and the CDJ Pitch is out of 00.00%.

Has anyone else had this problem?

Thank you Very much!!!

jrsmi9, 2019-03-27:
Hi, I have finished building 2 now, both of them have this same issue.
However I was not worried about it as it only occurs after the song is finished playing, by which time the channel faders on the mixer are down and the song is completely mixed out.

jrsmi9, 2019-03-27:
nice job with the tsopp board you made by the way, it is much cleaner than mine!

fabiodj2, 2019-03-27:
Hi...I'm working on the electronic part, how to make printed circuit board and do some mechanical and electronic adjustments in the set to become more friendly to do the complete design.

In the internal part of the CDJ control, for example, I will install a flatcable with female and male connector, in the part of the board TSOIP I used a circuit board already with holes and double face. I made the 3D impression of the Case in ABS for added strength.

In my project I will make the Kit be reversible, that is, if the person wants to return the CDJ 1000 MK3 to its original state it will be possible!

If I can help and contribute with this electronic part, I am available, even if they want soon I will be able to send to you the circuit boards ready to level near professional. I am very excited about the project and spending enough time and energy to see it close to 100%.

angusmack, 2019-03-27:
Hi - thank you for raising the concerns about the digital noise.

Unfortunately family and work does not allow me time to work on this at the moment :-(

I have complete electronic components for 2 mods, 2 CDJ1000Mk3 I bought from eBay a few months ago sitting at home ready to modify.

I have got as far as getting a development environment setup and I am able to build and deploy the firmware to the MCU and I have started on the electronic by soldering the TSOP board.

Please - if you have PCBs and design for simplifying the electronics side of things then please do share. The PCB files shared originally that I have in this repo are incomplete and I tried to get them in a format that a PCB printing house would accept but I kept getting validation errors (around solder masks etc.)

So, if you can share your findings please do upload them to this repo and share what you can. I am really looking forward to getting mine modded.

I have also been looking at micro SD to SD card sockets, to mount on the top/side of the case, as well as a micro USB to USB A socket to also mount in an easy to access position to allow Nexus-style ease of use.

I look forward to seeing all your input. I am just frustrated that I do not really have the time right now.

jrsmi9, 2019-03-28:
With regard to the errors with the PCB files shared originally, the company I used was: https://www.allpcb.com/

The format was fine according to allpcb, and they printed with no trouble, however I had them printed with no soldermask/drilling etc, just plain copper traces, so it may be different if you wanted something other than plain copper traces. I hope that helps.

Also with the micro sd to sd socket, i used a flat ribbon extension cable like this one:
(micro SD-SD)
https://www.ebay.com.au/itm/Micro-SD-TO-SD-Card-Extension-Cable-Adapter-Extender-Converter-for-SD-RS-MMC-SDH/162837010654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

or this one: (micro SD-micro SD extension)
https://www.ebay.com.au/itm/Micro-SD-TO-TF-Memory-Card-Extension-Cable-Adapter-Extender-Converter-For-GPS-AU/283378436231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

I then removed the original CDJ 1000 mk3 SD card circuit board, and placed the extension cable in its spot so it is all tucked away neatly.
Ill take a photo when I'm back home to show it properly to you all

fabiodj2, 2019-03-28:
HI jrsmi9...Excellent shared tips ... as incredible as it seems I did the same as you with regards to the CF Card extender ... I believe that this way the project gets really good. I only had a slight problem of "interference" using the extender, every time I'm using it the Tag List page opens itself. I'm investigating what might be happening.

jrsmi9, 2019-04-03:
[Vinyl Label.pdf](https://github.com/angusmack/CDJ-1000Mk3-MCU-Mod/files/3037951/Vinyl.Label.pdf)
Hi again, I forgot to share this earlier:
Because the case I designed to be 3D printed does not have the exact same dimensions as the one Andrei specified in his manual, I also had to re-size and change the vinyl sticker a little so that it fits the STL case file properly. Have attached the modified one that fits the STL file here (hopefully) :)

vincentdallamacchia, 2019-04-05:
ciao a tutti ... sto aspettando di ricevere il cdj 1000 nk3 per poter fare la mod ...ho già completato le schede stm e anchio ho riscontrato questa interferenza della pagina tag list che a volte si apre da sola .... so che al momento non ci sono ancora loop e hot cue ... qualcuno ha delle novità su firmware nuovi con nuove funzioni ??grazie

jrsmi9, 2019-04-07:
I tried to post this the other day but it did not work, however here is the vinyl sticker pdf for the 3D printed case files, as the STL file I designed has slightly different dimensions to the case Andrei originally specified in his manual
[Vinyl Label.pdf](https://github.com/angusmack/CDJ-1000Mk3-MCU-Mod/files/3051494/Vinyl.Label.pdf)

angusmack, 2019-04-17:
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
I tried to submit and got the following error from them:

"There is no trace and drills in files，please kindly provide gerber files as RS-274-X TYPE"

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

> I then removed the original CDJ 1000 mk3 SD card circuit board, and placed the extension cable in its spot so it is all tucked away neatly. The 3D printed case files I made are sized to fit those extension cables correctly.
> Ill take a photo when I'm back home to show it properly to you all

Please do share this. Can you upload into the images folder please?

Also, if you want to edit the main page or add as new page with your method and results then please do this also.

jrsmi9, 2019-04-17:
Yes, I emailed them saying i didn't require drills, however I'm not sure about file type?
Also I get an error saying i require push access to the repository in order to upload the image files, sorry I've not much experience with git hub

I'll comment them here in the meantime

[SD.zip](https://github.com/angusmack/CDJ-1000Mk3-MCU-Mod/files/3090078/SD.zip)
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

jrsmi9, 2019-04-17:
The only reason I can think of for the trace, is on their website did you tick the solder mask section as 'none' while uploading?

fabiodj2, 2019-04-18:
First version of PCB and Skin for CDJ...
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

DJJuciel, 2020-12-29:
Good night everyone, all right?
I hope you are all well! ... ah I apologize for my English, because I am using the translator ... so, I saw Fabio Lisboa's video and photos of everyone who shared here, and I noticed the TSSOP to DIP sign from you , ours were very good, if you don't mind, you could make the scheme available or, send photos of how you did it, in the electronics I'm curious or hobbyist, and our plate of you were top, much better than the one in the documentation, if you can send me I will be forever grateful! my email:
deejayjuciel@gmail.com

djludo62, 2022-04-02:
> First version of PCB and Skin for CDJ... 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

Hello would it be possible to order the same creation from you, because I don't know how to do it please thank you.

fabiodj2, 2022-04-03:
>

Hi,

I have the PCB kits ready and tested for the CDJs.  If you want and don't have experience with electronics, I can send you the ready set.

Closed 2022-04-03.

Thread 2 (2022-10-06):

Project still active?

snodecoder, 2022-10-06:
Hi!
I have been following this project for quite some time and I really applaud all the work you, djgreeb and others poured in to this!

I instantly bought a pair of cdj1000 mk3s when I heard of this project, but I'm still waiting for USB support before I start the modification.

I am happy to help (and with me a lot others) to further develop this amazing project. I have some decent C knowledge, but the STM32 environment is still new to me. But I am a quick learner ;)

Can you share with us the current status of the project and the obstacles / challenges you've encountered?

I think for example, one of the most requested features is proper USB support. From what I have found there is a good USB host library available for STM32. What are the challenges you are facing implementing this feature?

If you are still willing to work on this project would it be an idea to create a publicly available project board with features, their development status and possible issues? So we as the community can collectively work on this project to fully unlock it's amazing potential :)

angusmack, 2022-11-06:
Hi,

Current state of the project is that I haven't moved it on. Sadly work and family life have prevented from spending any time on this.

I have 2 CDJ1000 MK3 that I bought for a good price from eBay some time ago and all the parts in the BOM that Adrei shared but apart from that I have had very little time to spend on this project.

I was able to compile the source code as is and deploy to the STM and it appeared to work fine.

The other issue I had was that until 2 months ago I was not a Rekordbox user. Now that I am I may have time to look into reviving this more.

It would be great if you could think about adding some of the features most asked for e.g. the USB support that you mentioned.

You should be able to make a start and compile the code and start implementing the new features. If you need any more information then please let me know and I will make sure I monitor this repo a bit more closely than I have been.

Thank you for your interest and support in this project.

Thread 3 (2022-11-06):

Improvements in cpu

freddykat, 2022-11-06:
Hello,
Looking to have a word with you about an hardware improvement and firmware port.
Possible rpi4....

angusmack, 2022-11-06:
Hi,

Always happy to listen to any feedback, improvements, suggestions etc.

This is an open forum so please share your ideas. As you will see from the Readme doc this project originally belongs to Andrei so it is his work and I am simply hosting the source code and all the other files and content together in one place.

It would be great to hear what your thoughts were and any new ideas you might have.

Thanks.

freddykat, 2022-11-06:
The original developer used a arm board to develop this device but as per his guide master tempo would not workdue to insuficient cpu power.
Also RPI4 have RJ45 to try to implement the LINK funcktion.

Im only used arduino for esp and such.... im a bit limited in terms of programing, but maybe we can migrate to a more friendly hardware.
Currently use 4x cdj400 via midi to traktor and djm800 as mixer.

djokenzi, 2022-12-06:
I would love to see this project built on Raspberry Pi, with added USB and MP3 support and better looping functionality.

freddykat, 2023-08-28:
> I would love to see this project built on Raspberry Pi, with added USB and MP3 support and better looping functionality.

I was looking for someone to point me the right direction on porting the project for a Rpi4.
Hardware wise i think would be enough.

I have sort of dreamed to buy the plastic caps for the buttons missing between cdj1000 and cdj2000nsx2 (slip, and such) and use adicional GPIOS to drive those buttons and LEDS.
Im trying to make a 2000 clone based on 1000's, and i even found a quite similar touch strip to try to mimic them....

If anyone have a ideia how to port the system between stm32 and a rpi?

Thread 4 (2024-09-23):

Pcbkicad

mtoonk, 2024-09-23:
I am getting errors while ordering the pcb at jlcpcb (no drills and no top solder mask). Do you have original kicad files for the pcb?

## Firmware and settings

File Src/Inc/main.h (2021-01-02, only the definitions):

#define LCD_B0_Pin GPIO_PIN_4
#define LCD_B0_GPIO_Port GPIOE
#define QSPI_D2_Pin GPIO_PIN_2
#define QSPI_D2_GPIO_Port GPIOE
#define FMC_NBL1_Pin GPIO_PIN_1
#define FMC_NBL1_GPIO_Port GPIOE
#define FMC_NBL0_Pin GPIO_PIN_0
#define FMC_NBL0_GPIO_Port GPIOE
#define LED_BROWSE_Pin GPIO_PIN_8
#define LED_BROWSE_GPIO_Port GPIOB
#define KEY_INFO_Pin GPIO_PIN_4
#define KEY_INFO_GPIO_Port GPIOB
#define SWO_Pin GPIO_PIN_3
#define SWO_GPIO_Port GPIOB
#define SDMMC_CK_Pin GPIO_PIN_12
#define SDMMC_CK_GPIO_Port GPIOC
#define ENC_B_Pin GPIO_PIN_15
#define ENC_B_GPIO_Port GPIOA
#define ENC_B_EXTI_IRQn EXTI15_10_IRQn
#define SWCLK_Pin GPIO_PIN_14
#define SWCLK_GPIO_Port GPIOA
#define SWDIO_Pin GPIO_PIN_13
#define SWDIO_GPIO_Port GPIOA
#define LED_TAG_LIST_Pin GPIO_PIN_9
#define LED_TAG_LIST_GPIO_Port GPIOB
#define VCP_RX_Pin GPIO_PIN_7
#define VCP_RX_GPIO_Port GPIOB
#define QSPI_NCS_Pin GPIO_PIN_6
#define QSPI_NCS_GPIO_Port GPIOB
#define FMC_SDNCAS_Pin GPIO_PIN_15
#define FMC_SDNCAS_GPIO_Port GPIOG
#define LCD_B1_Pin GPIO_PIN_13
#define LCD_B1_GPIO_Port GPIOJ
#define OTG_FS_VBUS_Pin GPIO_PIN_12
#define OTG_FS_VBUS_GPIO_Port GPIOJ
#define FMC_D2_Pin GPIO_PIN_0
#define FMC_D2_GPIO_Port GPIOD
#define SDMMC_D3_Pin GPIO_PIN_11
#define SDMMC_D3_GPIO_Port GPIOC
#define SDMMC_D2_Pin GPIO_PIN_10
#define SDMMC_D2_GPIO_Port GPIOC
#define NC1_Pin GPIO_PIN_8
#define NC1_GPIO_Port GPIOI
#define SAI2_MCLKA_Pin GPIO_PIN_4
#define SAI2_MCLKA_GPIO_Port GPIOI
#define LCD_DE_Pin GPIO_PIN_7
#define LCD_DE_GPIO_Port GPIOK
#define LCD_B7_Pin GPIO_PIN_6
#define LCD_B7_GPIO_Port GPIOK
#define LCD_B6_Pin GPIO_PIN_5
#define LCD_B6_GPIO_Port GPIOK
#define LCD_B4_Pin GPIO_PIN_12
#define LCD_B4_GPIO_Port GPIOG
#define SAI2_SDB_Pin GPIO_PIN_10
#define SAI2_SDB_GPIO_Port GPIOG
#define LCD_B2_Pin GPIO_PIN_14
#define LCD_B2_GPIO_Port GPIOJ
#define OTG_FS_PowerSwitchOn_Pin GPIO_PIN_5
#define OTG_FS_PowerSwitchOn_GPIO_Port GPIOD
#define FMC_D3_Pin GPIO_PIN_1
#define FMC_D3_GPIO_Port GPIOD
#define ENC_BUTTON_Pin GPIO_PIN_2
#define ENC_BUTTON_GPIO_Port GPIOI
#define uSD_Detect_Pin GPIO_PIN_13
#define uSD_Detect_GPIO_Port GPIOC
#define FMC_A0_Pin GPIO_PIN_0
#define FMC_A0_GPIO_Port GPIOF
#define SAI2_SCKA_Pin GPIO_PIN_5
#define SAI2_SCKA_GPIO_Port GPIOI
#define SAI2_FSA_Pin GPIO_PIN_7
#define SAI2_FSA_GPIO_Port GPIOI
#define LCD_HSYNC_Pin GPIO_PIN_10
#define LCD_HSYNC_GPIO_Port GPIOI
#define SAI2_SDA_Pin GPIO_PIN_6
#define SAI2_SDA_GPIO_Port GPIOI
#define LCD_B5_Pin GPIO_PIN_4
#define LCD_B5_GPIO_Port GPIOK
#define LCD_BL_CTRL_Pin GPIO_PIN_3
#define LCD_BL_CTRL_GPIO_Port GPIOK
#define LCD_B3_Pin GPIO_PIN_15
#define LCD_B3_GPIO_Port GPIOJ
#define OTG_FS_OverCurrent_Pin GPIO_PIN_4
#define OTG_FS_OverCurrent_GPIO_Port GPIOD
#define SDMMC_D0_Pin GPIO_PIN_2
#define SDMMC_D0_GPIO_Port GPIOD
#define TP3_Pin GPIO_PIN_15
#define TP3_GPIO_Port GPIOH
#define LED_INFO_Pin GPIO_PIN_1
#define LED_INFO_GPIO_Port GPIOI
#define FMC_A1_Pin GPIO_PIN_1
#define FMC_A1_GPIO_Port GPIOF
#define LCD_DISP_Pin GPIO_PIN_12
#define LCD_DISP_GPIO_Port GPIOI
#define LCD_VSYNC_Pin GPIO_PIN_9
#define LCD_VSYNC_GPIO_Port GPIOI
#define KEY_BACK_Pin GPIO_PIN_0
#define KEY_BACK_GPIO_Port GPIOI
#define VCP_TX_Pin GPIO_PIN_9
#define VCP_TX_GPIO_Port GPIOA
#define LCD_G6_Pin GPIO_PIN_1
#define LCD_G6_GPIO_Port GPIOK
#define LCD_G7_Pin GPIO_PIN_2
#define LCD_G7_GPIO_Port GPIOK
#define ENC_A_Pin GPIO_PIN_8
#define ENC_A_GPIO_Port GPIOA
#define OSC_25M_Pin GPIO_PIN_0
#define OSC_25M_GPIO_Port GPIOH
#define FMC_A2_Pin GPIO_PIN_2
#define FMC_A2_GPIO_Port GPIOF
#define LCD_INT_Pin GPIO_PIN_13
#define LCD_INT_GPIO_Port GPIOI
#define LCD_INT_EXTI_IRQn EXTI15_10_IRQn
#define LCD_R0_Pin GPIO_PIN_15
#define LCD_R0_GPIO_Port GPIOI
#define LCD_G4_Pin GPIO_PIN_11
#define LCD_G4_GPIO_Port GPIOJ
#define LCD_G5_Pin GPIO_PIN_0
#define LCD_G5_GPIO_Port GPIOK
#define KEY_TAG_LIST_Pin GPIO_PIN_7
#define KEY_TAG_LIST_GPIO_Port GPIOC
#define FMC_A3_Pin GPIO_PIN_3
#define FMC_A3_GPIO_Port GPIOF
#define LCD_CLK_Pin GPIO_PIN_14
#define LCD_CLK_GPIO_Port GPIOI
#define LCD_G1_Pin GPIO_PIN_8
#define LCD_G1_GPIO_Port GPIOJ
#define LCD_G3_Pin GPIO_PIN_10
#define LCD_G3_GPIO_Port GPIOJ
#define FMC_SDCLK_Pin GPIO_PIN_8
#define FMC_SDCLK_GPIO_Port GPIOG
#define KEY_MENU_Pin GPIO_PIN_6
#define KEY_MENU_GPIO_Port GPIOC
#define FMC_A4_Pin GPIO_PIN_4
#define FMC_A4_GPIO_Port GPIOF
#define FMC_SDNME_Pin GPIO_PIN_5
#define FMC_SDNME_GPIO_Port GPIOH
#define FMC_SDNE0_Pin GPIO_PIN_3
#define FMC_SDNE0_GPIO_Port GPIOH
#define LCD_G0_Pin GPIO_PIN_7
#define LCD_G0_GPIO_Port GPIOJ
#define LCD_G2_Pin GPIO_PIN_9
#define LCD_G2_GPIO_Port GPIOJ
#define KEY_TAG_TRACK_Pin GPIO_PIN_7
#define KEY_TAG_TRACK_GPIO_Port GPIOG
#define KEY_BROWSE_Pin GPIO_PIN_6
#define KEY_BROWSE_GPIO_Port GPIOG
#define KEY_MIDI_Pin GPIO_PIN_7
#define KEY_MIDI_GPIO_Port GPIOF
#define LED_MIDI_Pin GPIO_PIN_6
#define LED_MIDI_GPIO_Port GPIOF
#define FMC_A5_Pin GPIO_PIN_5
#define FMC_A5_GPIO_Port GPIOF
#define NC2_Pin GPIO_PIN_2
#define NC2_GPIO_Port GPIOH
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

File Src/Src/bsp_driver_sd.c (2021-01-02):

/**
 ******************************************************************************
  * @file    bsp_driver_sd.c for F7 (based on stm32756g_eval_sd.c)
  * @brief   This file includes a generic uSD card driver.
  ******************************************************************************
  * This notice applies to any and all portions of this file
  * that are not between comment pairs USER CODE BEGIN and
  * USER CODE END. Other portions of this file, whether 
  * inserted by the user or by software development tools
  * are owned by their respective copyright owners.
  *
  * Copyright (c) 2020 STMicroelectronics International N.V. 
  * All rights reserved.
  *
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
  ******************************************************************************
  */

#define BUS_4BITS 1

#ifdef OLD_API
/* kept to avoid issue when migrating old projects. */
/* USER CODE BEGIN 0 */

/* Includes ------------------------------------------------------------------*/
#include "bsp_driver_sd.h"

/* Extern variables ---------------------------------------------------------*/ 
  
extern SD_HandleTypeDef _HSD;
extern HAL_SD_CardInfoTypedef _SD_CARD_INFO; 

/**
  * @brief  Initializes the SD card device.
  * @retval SD status
  */
uint8_t BSP_SD_Init(void)
{
  uint8_t sd_state = MSD_OK;
  /* Check if the SD card is plugged in the slot */
  if (BSP_SD_IsDetected() != SD_PRESENT)
  {
    return MSD_ERROR_SD_NOT_PRESENT;
  }
  /* HAL SD initialization */
  sd_state = HAL_SD_Init(&_HSD, &_SD_CARD_INFO);
#ifdef BUS_4BITS
  /* Configure SD Bus width */
  if (sd_state == MSD_OK)
  {
    /* Enable wide operation */
    if (HAL_SD_WideBusOperation_Config(&_HSD, SDMMC_BUS_WIDE_4B) != SD_OK)
    {
      sd_state = MSD_ERROR;
    }
    else
    {
      sd_state = MSD_OK;
    }
  }
#endif
  return sd_state;
}

/**
  * @brief  Configures Interrupt mode for SD detection pin.
  * @retval Returns 0 in success otherwise 1. 
  */
uint8_t BSP_SD_ITConfig(void)
{  
  /* TBI: add user code here depending on the hardware configuration used */
  
  return (uint8_t)0;
}

/**
  * @brief  Reads block(s) from a specified address in an SD card, in polling mode. 
  * @param  pData: Pointer to the buffer that will contain the data to transmit
  * @param  ReadAddr: Address from where data is to be read  
  * @param  BlockSize: SD card data block size, that should be 512
  * @param  NumOfBlocks: Number of SD blocks to read 
  * @retval SD status
  */
uint8_t BSP_SD_ReadBlocks(uint32_t *pData, uint64_t ReadAddr, uint32_t BlockSize, uint32_t NumOfBlocks)
{
  uint8_t sd_state;
  if(HAL_SD_ReadBlocks(&_HSD, pData, ReadAddr, BlockSize, NumOfBlocks) != SD_OK)  
  {
    sd_state = MSD_ERROR;
  }
  else
  {
    sd_state = MSD_OK;
  }
  return sd_state;  
}

/**
  * @brief  Writes block(s) to a specified address in an SD card, in polling mode. 
  * @param  pData: Pointer to the buffer that will contain the data to transmit
  * @param  WriteAddr: Address from where data is to be written  
  * @param  BlockSize: SD card data block size, that should be 512
  * @param  NumOfBlocks: Number of SD blocks to write
  * @retval SD status
  */
uint8_t BSP_SD_WriteBlocks(uint32_t *pData, uint64_t WriteAddr, uint32_t BlockSize, uint32_t NumOfBlocks)
{
  uint8_t sd_state;
  if(HAL_SD_WriteBlocks(&_HSD, pData, WriteAddr, BlockSize, NumOfBlocks) != SD_OK)  
  {
    sd_state = MSD_ERROR;
  }
  else
  {
    sd_state = MSD_OK;
  }
  return sd_state;  
}

/**
  * @brief  Reads block(s) from a specified address in an SD card, in DMA mode.
  * @param  pData: Pointer to the buffer that will contain the data to transmit
  * @param  ReadAddr: Address from where data is to be read  
  * @param  BlockSize: SD card data block size, that should be 512
  * @param  NumOfBlocks: Number of SD blocks to read 
  * @retval SD status
  */
uint8_t BSP_SD_ReadBlocks_DMA(uint32_t *pData, uint64_t ReadAddr, uint32_t BlockSize, uint32_t NumOfBlocks)
{
  uint8_t sd_state = MSD_OK;
  
  /* Read block(s) in DMA transfer mode */
  if(HAL_SD_ReadBlocks_DMA(&_HSD, pData, ReadAddr, BlockSize, NumOfBlocks) != SD_OK)  
  {
    sd_state = MSD_ERROR;
  }
  
  /* Wait until transfer is complete */
  if(sd_state == MSD_OK)
  {
    if(HAL_SD_CheckReadOperation(&_HSD, (uint32_t)SD_DATATIMEOUT) != SD_OK)  
    {
      sd_state = MSD_ERROR;
    }
    else
    {
      sd_state = MSD_OK;
    }
  }
  
  return sd_state; 
}

/**
  * @brief  Writes block(s) to a specified address in an SD card, in DMA mode.  
  * @param  pData: Pointer to the buffer that will contain the data to transmit
  * @param  WriteAddr: Address from where data is to be written  
  * @param  BlockSize: SD card data block size, that should be 512
  * @param  NumOfBlocks: Number of SD blocks to write 
  * @retval SD status
  */
uint8_t BSP_SD_WriteBlocks_DMA(uint32_t *pData, uint64_t WriteAddr, uint32_t BlockSize, uint32_t NumOfBlocks)
{
  uint8_t sd_state = MSD_OK;
  
  /* Write block(s) in DMA transfer mode */
  if(HAL_SD_WriteBlocks_DMA(&_HSD, pData, WriteAddr, BlockSize, NumOfBlocks) != SD_OK)  
  {
    sd_state = MSD_ERROR;
  }
  
  /* Wait until transfer is complete */
  if(sd_state == MSD_OK)
  {
    if(HAL_SD_CheckWriteOperation(&_HSD, (uint32_t)SD_DATATIMEOUT) != SD_OK)  
    {
      sd_state = MSD_ERROR;
    }
    else
    {
      sd_state = MSD_OK;
    }
  }
  
  return sd_state; 
}

/**
  * @brief  Erases the specified memory area of the given SD card. 
  * @param  StartAddr: Start byte address
  * @param  EndAddr: End byte address
  * @retval SD status
  */
uint8_t BSP_SD_Erase(uint64_t StartAddr, uint64_t EndAddr)
{
  uint8_t sd_state;
  if(HAL_SD_Erase(&_HSD, StartAddr, EndAddr) != SD_OK)  
  {
    sd_state = MSD_ERROR;
  }
  else
  {
    sd_state = MSD_OK;
  }
  return sd_state; 
}

/**
  * @brief  Gets the current SD card data status.
  * @retval Data transfer state.
  *          This value can be one of the following values:
  *            @arg  SD_TRANSFER_OK: No data transfer is acting
  *            @arg  SD_TRANSFER_BUSY: Data transfer is acting
  *            @arg  SD_TRANSFER_ERROR: Data transfer error 
  */
HAL_SD_TransferStateTypedef BSP_SD_GetStatus(void)
{
  return(HAL_SD_GetStatus(&_HSD));
}

/**
  * @brief  Get SD information about specific SD card.
  * @param  CardInfo: Pointer to HAL_SD_CardInfoTypedef structure
  */
void BSP_SD_GetCardInfo(HAL_SD_CardInfoTypedef* CardInfo)
{
  /* Get SD card Information */
  HAL_SD_Get_CardInfo(&_HSD, CardInfo);
}
/* USER CODE END 0 */
#else
/* USER CODE BEGIN FirstSection */
/* can be used to modify / undefine following code or add new definitions */
/* USER CODE END FirstSection */
/* Includes ------------------------------------------------------------------*/
#include "bsp_driver_sd.h"

/* Extern variables ---------------------------------------------------------*/ 
  
extern SD_HandleTypeDef _HSD;
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

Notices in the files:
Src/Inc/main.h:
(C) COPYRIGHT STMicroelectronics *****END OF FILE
